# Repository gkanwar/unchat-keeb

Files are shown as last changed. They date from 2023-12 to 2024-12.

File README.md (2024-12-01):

# Overview
This repository contains the design materials, firmware, and related docs for
two iterations (2023 and 2024) of the **"Unchat" keyboard**.  Highlights of this
design include:

 * An **ergonomic, split form keyboard** with 40 keys (2024) or 42 keys (2023)
 * **Custom Rust firmware** supporting QMK JSON keymaps using a limited feature set
 * **Hardware chatter mitigation** through Hall Effect magnetic switches (2024)
   or hardware debouncing circuitry (2023)
 * **Diode-free** using a 6-bit bus (2023) or 4-bit analog muxes (2024)

Here are some photos.

The **Unchat-42 (2023)**:
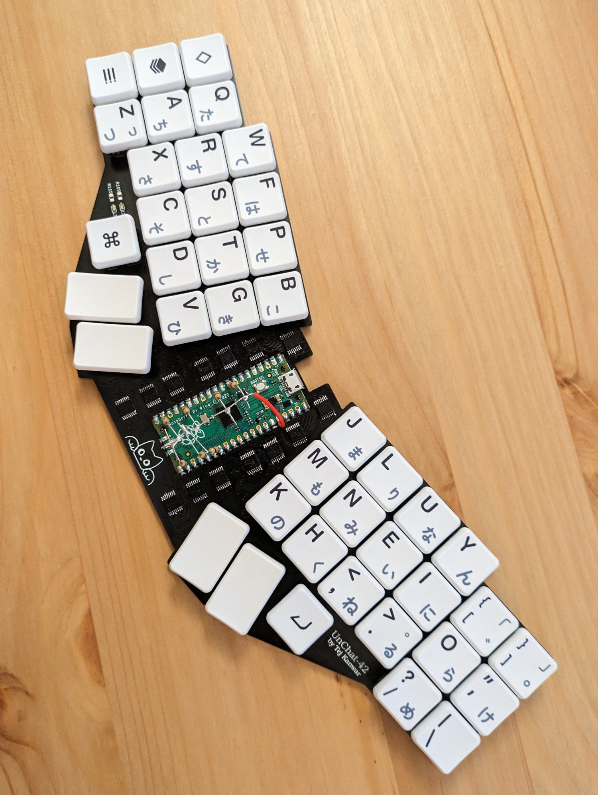
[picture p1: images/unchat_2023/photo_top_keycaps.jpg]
Top view of assembled 2023 kbd

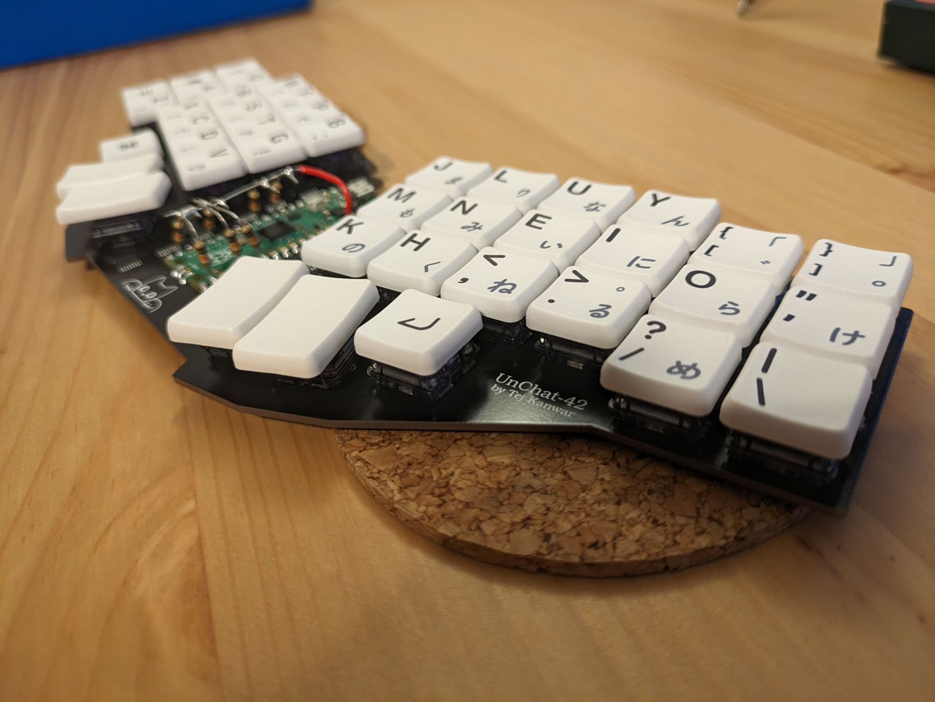
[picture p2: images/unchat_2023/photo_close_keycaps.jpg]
Close-up image of assembled 2023 kbd


Designing the PCB in Kicad and the results:
PCB design in Kicad
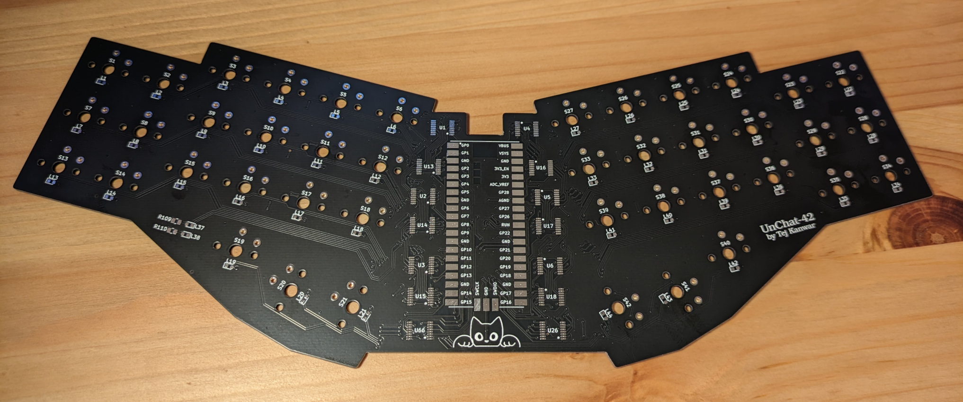
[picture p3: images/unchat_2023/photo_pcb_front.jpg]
Front view of 2023 pcb

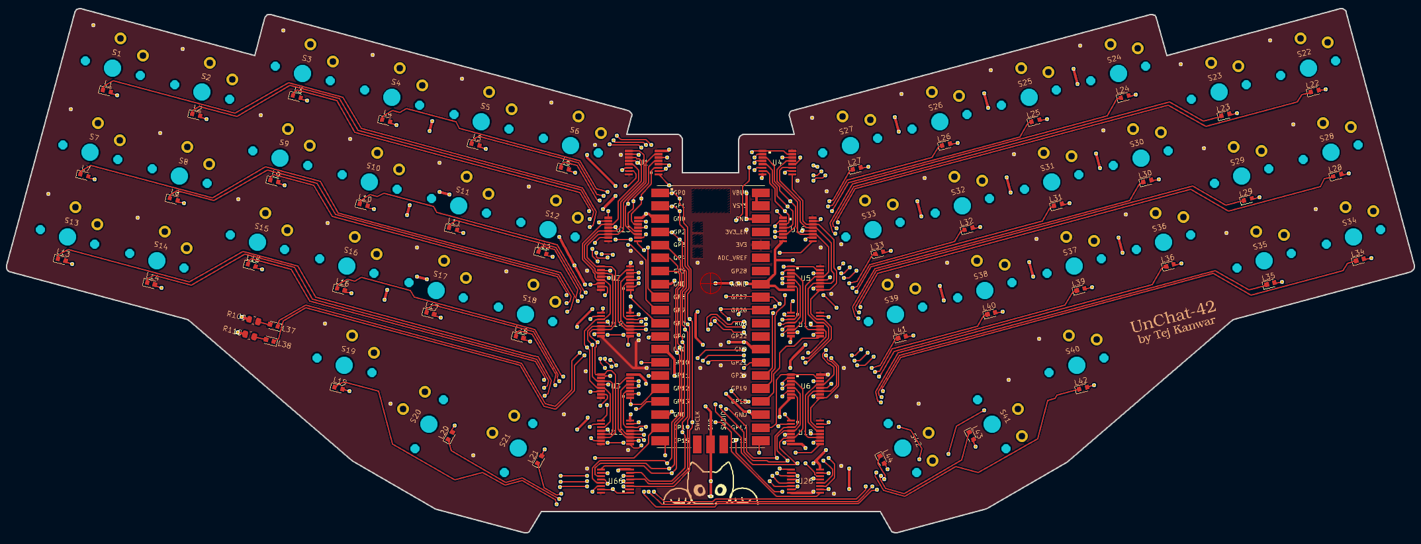
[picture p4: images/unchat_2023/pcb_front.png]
Front view of 2023 pcb design

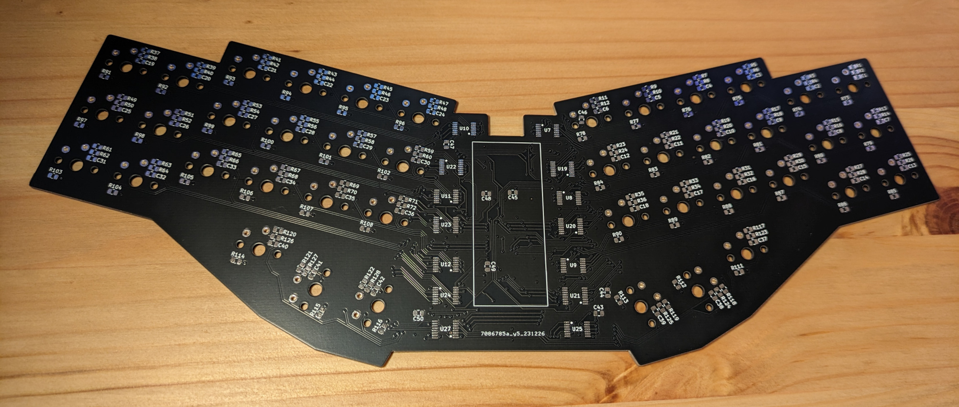
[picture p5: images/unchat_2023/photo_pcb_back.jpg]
Back view of 2023 pcb

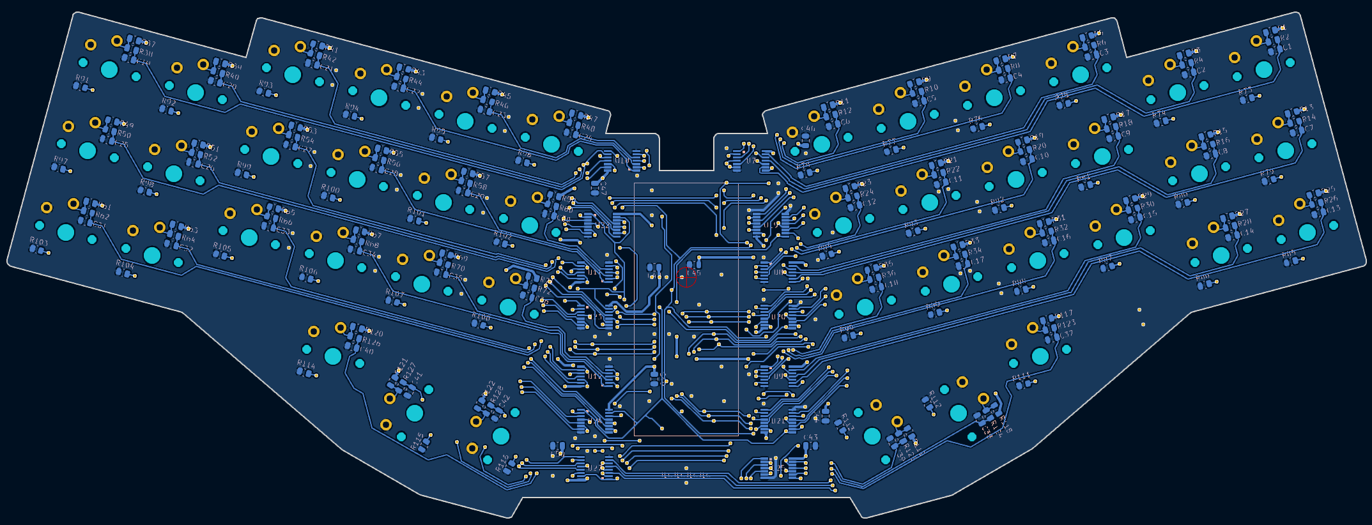
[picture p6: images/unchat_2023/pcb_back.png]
Back view of 2023 pcb design


The **Unchat-40 (2024)** (assembly still WIP):
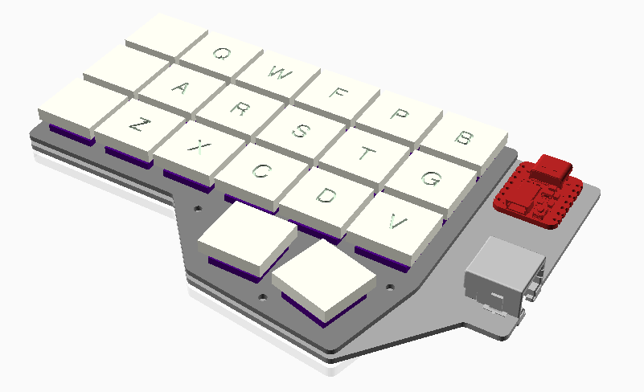
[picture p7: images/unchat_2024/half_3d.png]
3D design overview

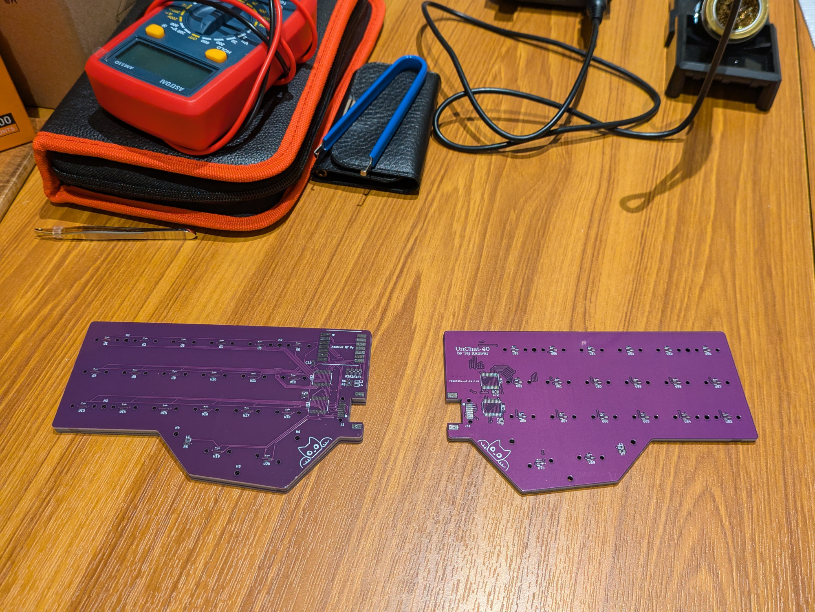
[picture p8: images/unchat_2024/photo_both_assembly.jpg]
Top view of assembled 2023 pcbs

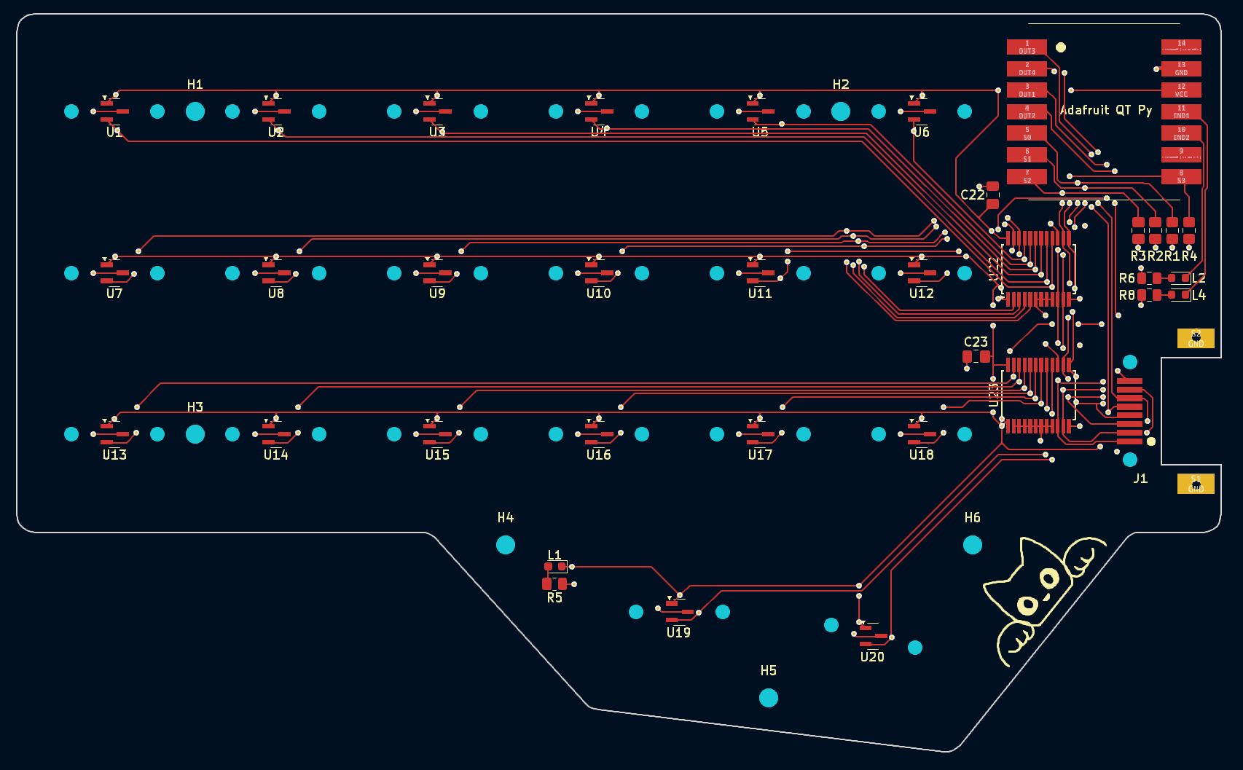
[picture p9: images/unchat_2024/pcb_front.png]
Front view of 2023 pcb

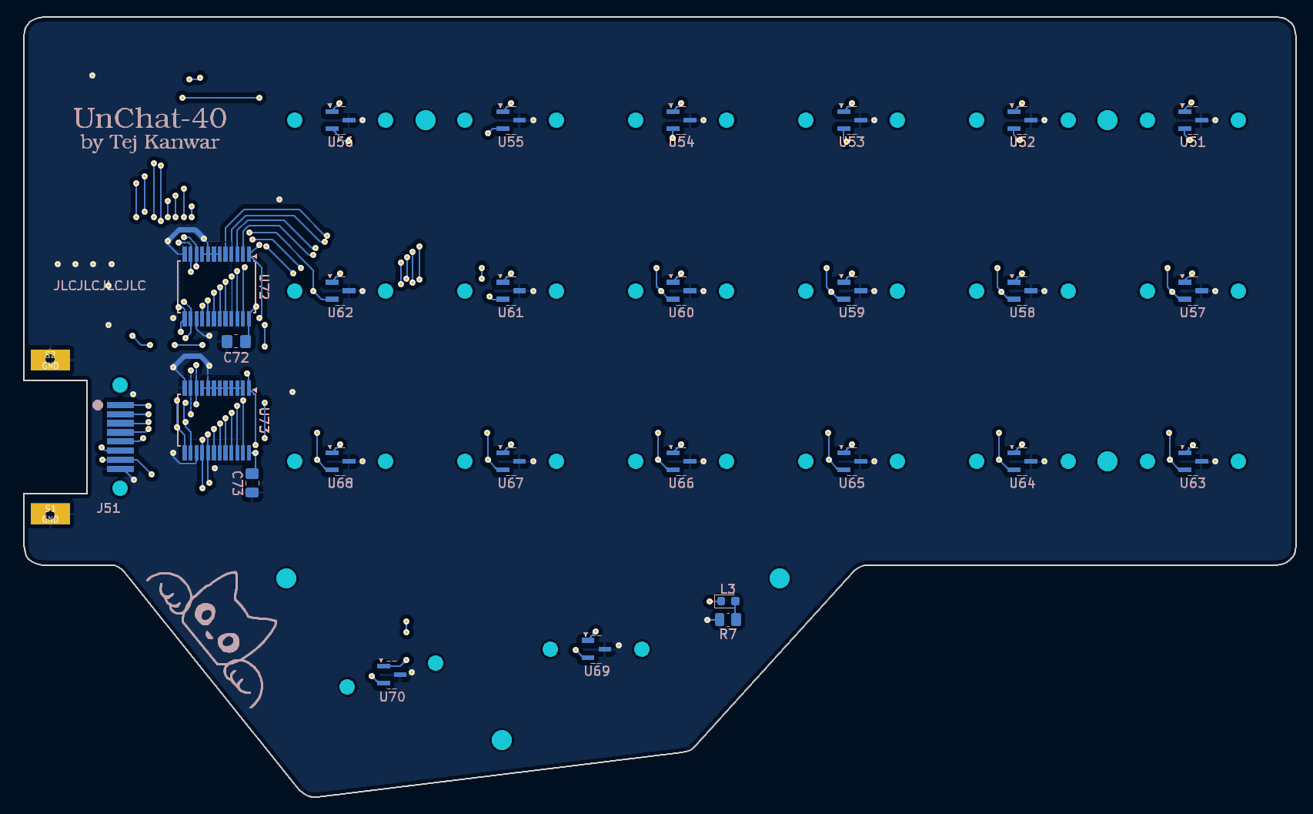
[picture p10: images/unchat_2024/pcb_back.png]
Back view of 2023 pcb


## Why design a custom keyboard?
This project was motivated in small part by wanting to solve frustrating key
chatter on my main keyboard and in larger part as a way to kill free time during
holiday seasons. It was an awesome way to learn several new skills. I recommend
this sort of project if any of these interest you as well:

 * PCB design in Kicad
 * Mechanical design in OpenSCAD
 * Electronic assembly and debugging
 * Embedded Rust

## Free to use and share
Designs and code in this repository are covered by the CC0 license, allowing
anyone to freely copy, modify, or distribute these materials. Attribution not
required.

That said, there are some known issues with the original designs. These are
documented below, along with my workarounds. In some cases, these issues are
corrected in the latest design files, but corrections have not been tested. You
may discover other issues that I have not personally encountered. **Use at your
own risk!**

# Unchat-40 (2024)

## Design overview
Summary of design features:

 * Two **reversible PCBs** connected via RJ45
 * Controlled by an **Adafruit QT Py RP2040**
 * **Hall-effect** switches queried via **analog muxes**
 * Acrylic and/or aluminum plate and frame

The 2023 design was fairly successful at reducing key chatter without software
debouncing, but I still experienced occasional chatter (see below).
Unfortunately, this was on timescales far above the filtering provided by the
hardware debouncing, likely due to corrosion and mechanical deformation in the
switches due to my terrible assembly process.

With this new 2024 design, I entirely circumvented using electrical contacts by
moving to a Hall Effect magnetic switch design. This is also used in some
"gaming-friendly" keyboards because it allows very rapid triggering, but from
the perspective of this design the main advantage is that we can apply
**hysteresis** to completely eliminate chatter. The cheap DRV5055 sensor
fit the design perfectly. Unfortunately, magnetic switches are still fairly
rare and a bit more pricey, but the overall cost was still manageable.

## Electronic design

## Mechanical design

## Cost breakdown

# Unchat-42 (2023)

More design info and post-mortem coming soon!

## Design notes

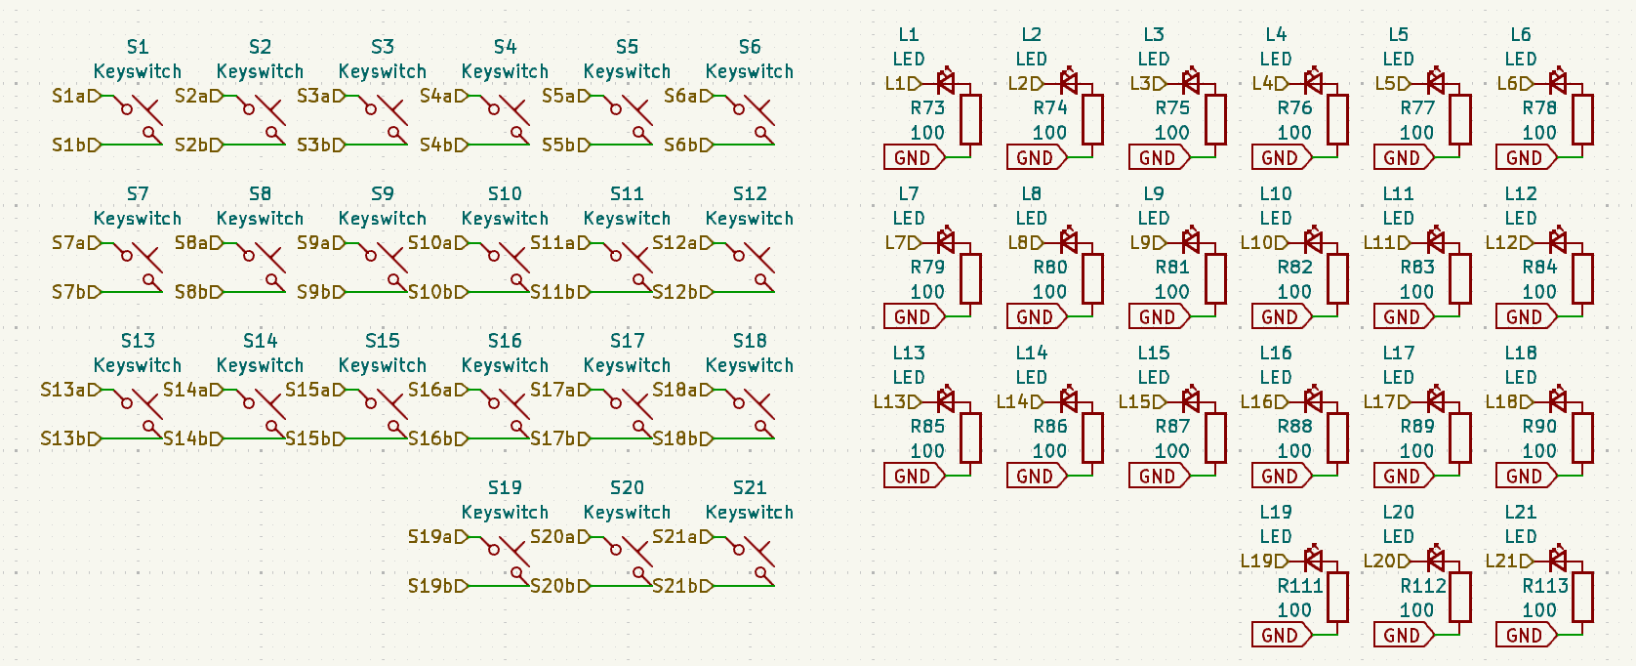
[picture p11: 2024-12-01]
images/unchat_2023/schematic_switches_leds.png

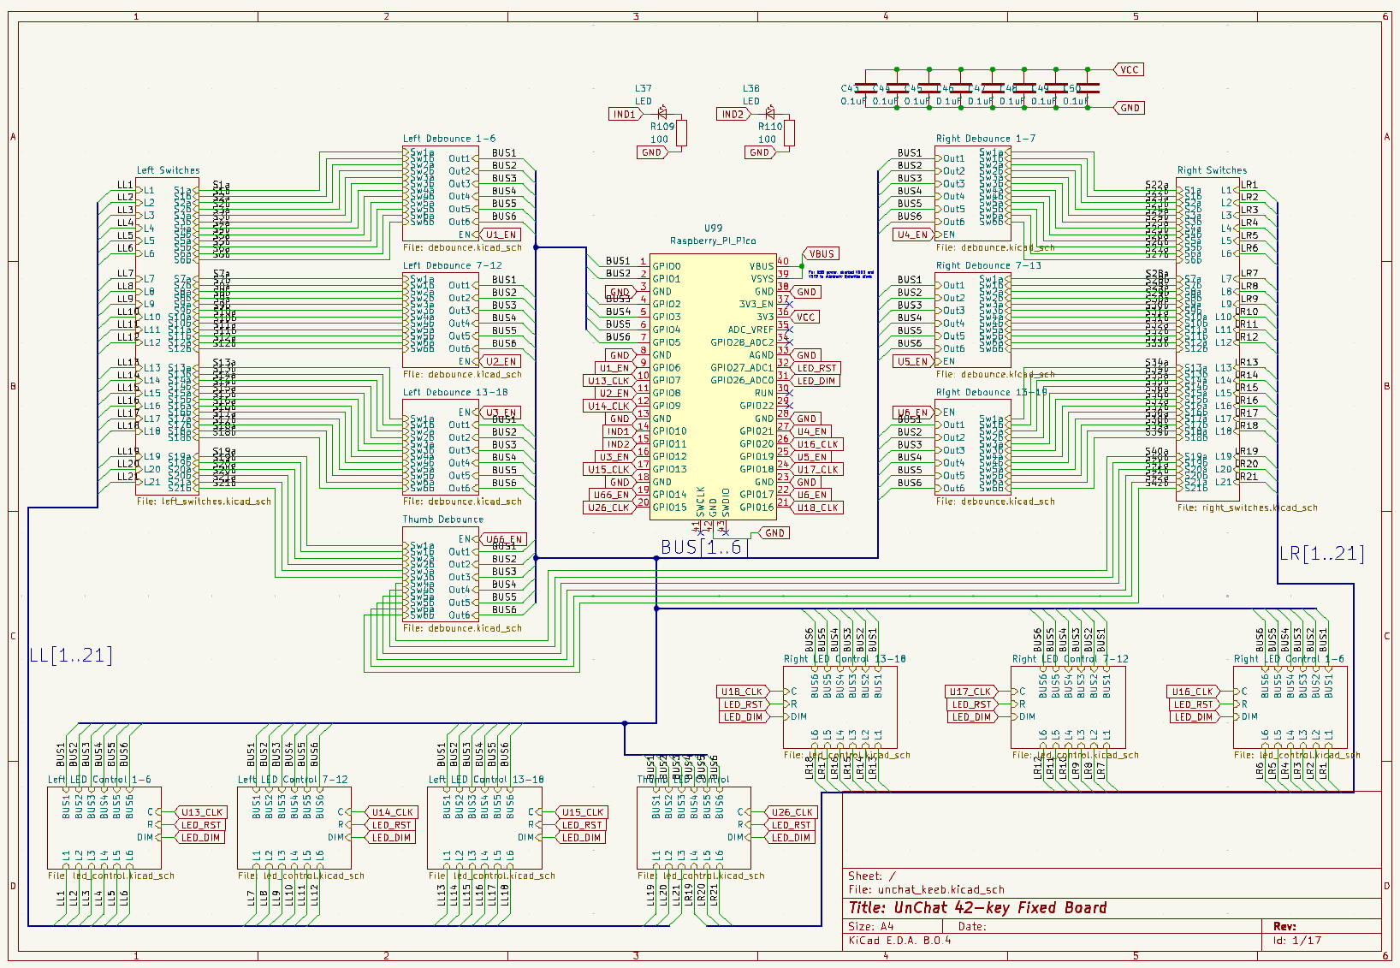
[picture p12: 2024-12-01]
images/unchat_2023/schematic_overview.png

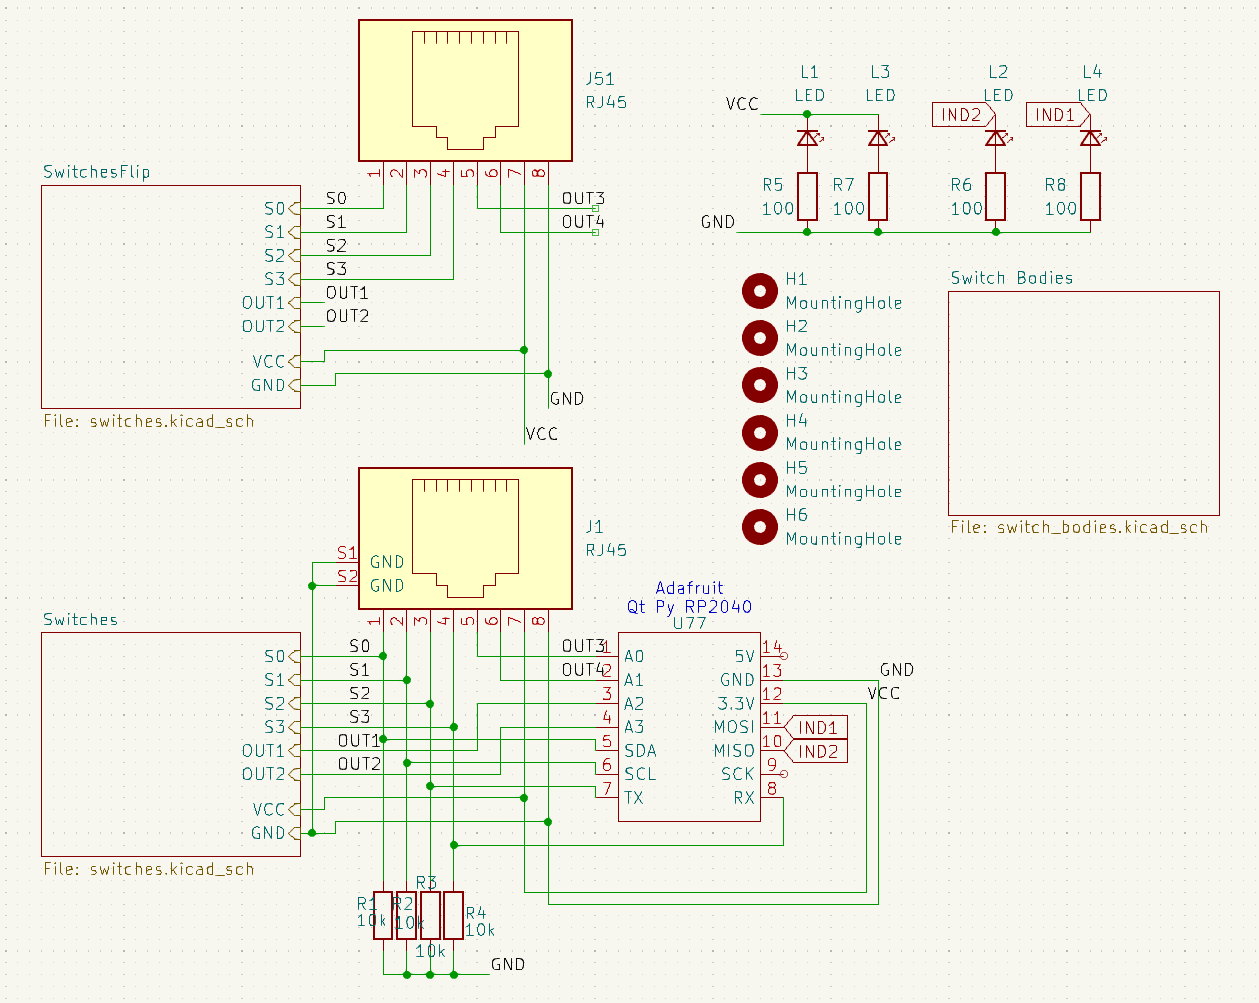
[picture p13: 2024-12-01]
images/unchat_2024/schematic_overview.png

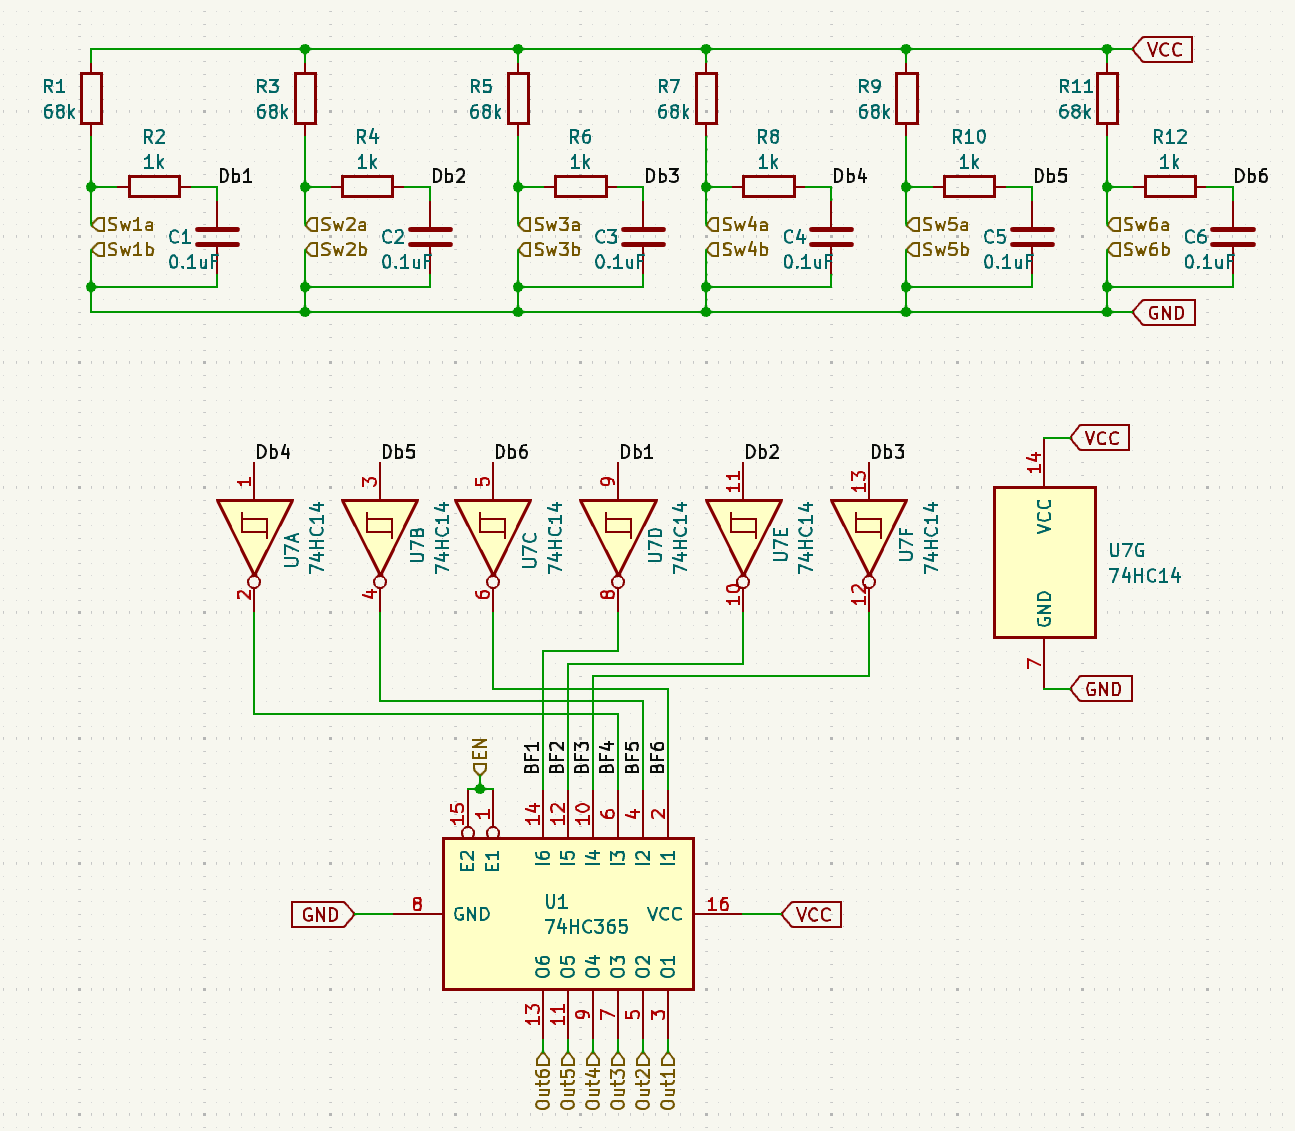
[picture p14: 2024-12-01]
images/unchat_2023/schematic_debounce.png

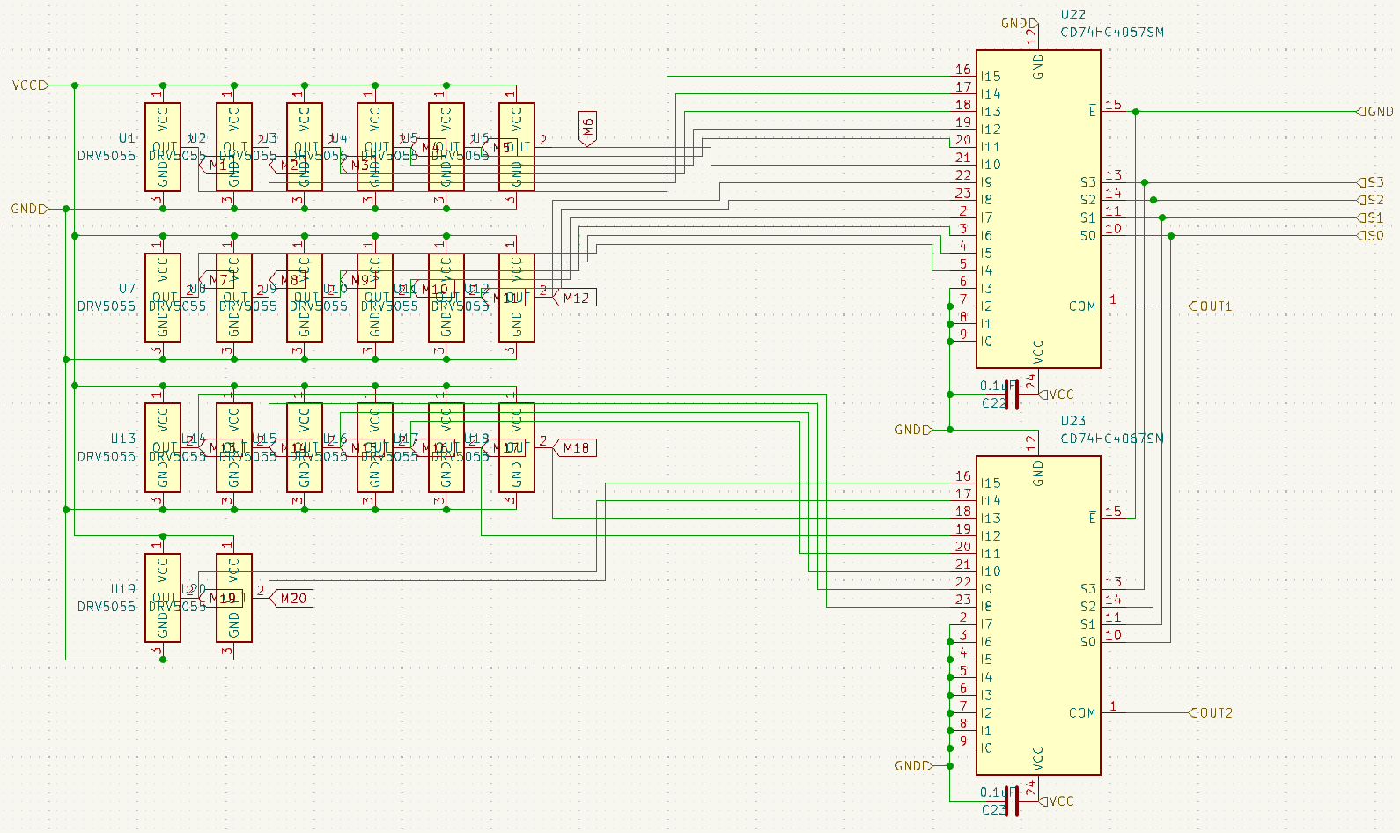
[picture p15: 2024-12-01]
images/unchat_2024/schematic_switches.png

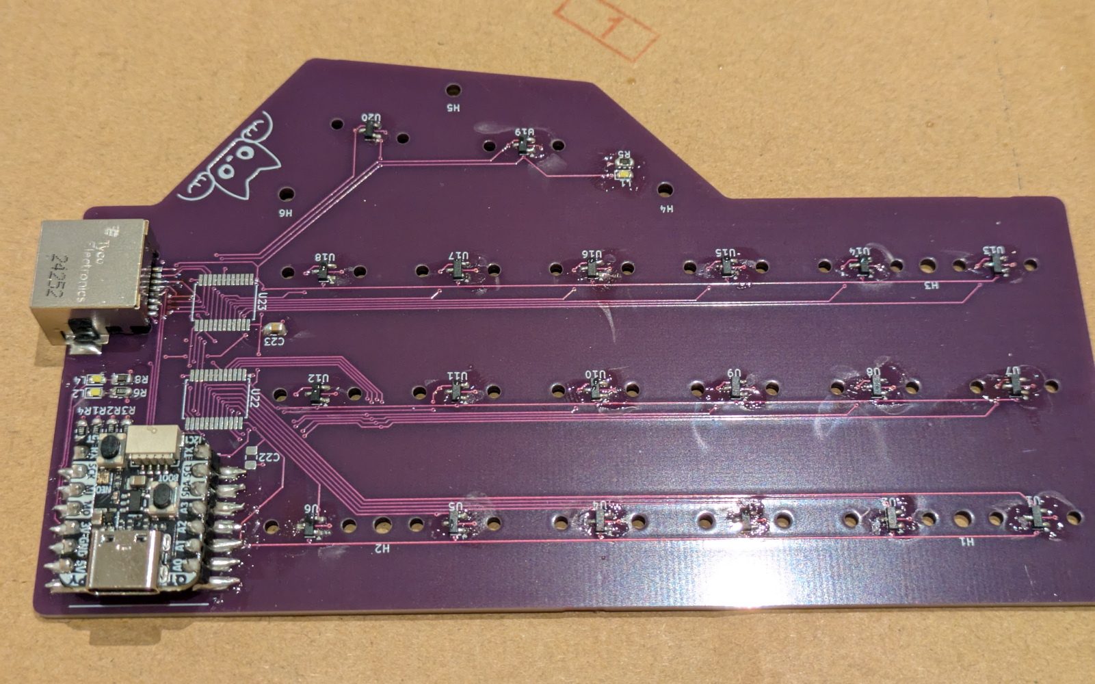
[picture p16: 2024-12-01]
images/unchat_2024/photo_lhs_no_keycaps.jpg

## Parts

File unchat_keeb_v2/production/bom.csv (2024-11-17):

Designator | Footprint | Quantity | Value | LCSC Part #
C22, C23, C72, C73 | 0805 | 4 | 0.1uF
J1 | TE_2041126-1_RJ45 | 1 | RJ45
J51 | TE_2041126-1_RJ45_Back | 1 | RJ45
L1, L2, L3, L4 | 0603 | 4 | LED
R1, R2, R3, R4 | 0805 | 4 | 10k
R5, R6, R7, R8 | 0805 | 4 | 100
S1, S10, S11, S12, S13, S14, S15, S16, S17, S18, S19, S2, S20, S3, S4, S5, S6, S7, S8, S9 | MX_HallEffect_Reversible_1.00u | 20 | Keyswitch
U1, U10, U11, U12, U13, U14, U15, U16, U17, U18, U19, U2, U20, U3, U4, U5, U51, U52, U53, U54, U55, U56, U57, U58, U59, U6, U60, U61, U62, U63, U64, U65, U66, U67, U68, U69, U7, U70, U8, U9 | SOT-23 | 40 | DRV5055
U22, U23, U72, U73 | SSOP-24_5.3x8.2mm_P0.65mm | 4 | CD74HC4067SM
U77 | Adafruit_QT_Py_SMD | 1 | ~

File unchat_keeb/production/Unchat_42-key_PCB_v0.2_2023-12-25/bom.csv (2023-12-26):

Designator | Footprint | Quantity | Value | LCSC Part #
C1, C10, C11, C12, C13, C14, C15, C16, C17, C18, C19, C2, C20, C21, C22, C23, C24, C25, C26, C27, C28, C29, C3, C30, C31, C32, C33, C34, C35, C36, C37, C38, C39, C4, C40, C41, C42, C43, C44, C45, C46, C47, C48, C49, C5, C50, C6, C7, C8, C9 | 0805 | 50 | 0.1uF
L1, L10, L11, L12, L13, L14, L15, L16, L17, L18, L19, L2, L20, L21, L22, L23, L24, L25, L26, L27, L28, L29, L3, L30, L31, L32, L33, L34, L35, L36, L37, L38, L39, L4, L40, L41, L42, L43, L44, L5, L6, L7, L8, L9 | 0603 | 44 | LED
R1, R11, R117, R118, R119, R120, R121, R122, R13, R15, R17, R19, R21, R23, R25, R27, R29, R3, R31, R33, R35, R37, R39, R41, R43, R45, R47, R49, R5, R51, R53, R55, R57, R59, R61, R63, R65, R67, R69, R7, R71, R9 | 0805 | 42 | 68k
R10, R12, R123, R124, R125, R126, R127, R128, R14, R16, R18, R2, R20, R22, R24, R26, R28, R30, R32, R34, R36, R38, R4, R40, R42, R44, R46, R48, R50, R52, R54, R56, R58, R6, R60, R62, R64, R66, R68, R70, R72, R8 | 0805 | 42 | 1k
R100, R101, R102, R103, R104, R105, R106, R107, R108, R109, R110, R111, R112, R113, R114, R115, R116, R73, R74, R75, R76, R77, R78, R79, R80, R81, R82, R83, R84, R85, R86, R87, R88, R89, R90, R91, R92, R93, R94, R95, R96, R97, R98, R99 | 0805 | 44 | 100
S1, S10, S11, S12, S13, S14, S15, S16, S17, S18, S19, S2, S22, S23, S24, S25, S26, S27, S28, S29, S3, S30, S31, S32, S33, S34, S35, S36, S37, S38, S39, S4, S40, S5, S6, S7, S8, S9 | Choc_V1_LED_1.00u | 38 | Keyswitch
S20, S21, S41, S42 | Choc_V1_LED_1.50u | 4 | Keyswitch
U1, U19, U2, U20, U21, U22, U23, U24, U27, U3, U4, U5, U6, U66 | TSSOP-16_4.4x5mm_P0.65mm | 14 | 74HC365
U10, U11, U12, U25, U7, U8, U9 | TSSOP-14_4.4x5mm_P0.65mm | 7 | 74HC14
U13, U14, U15, U16, U17, U18, U26 | TSSOP-16_4.4x5mm_P0.65mm | 7 | 74HC174
U99 | Raspberry_Pi_Pico_SMD | 1 | Raspberry_Pi_Pico

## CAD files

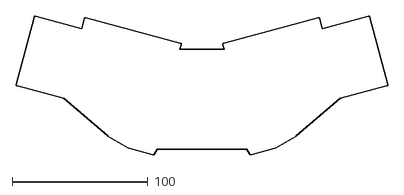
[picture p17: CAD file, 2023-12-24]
cad/pcb.dxf
274.1 x 102.0

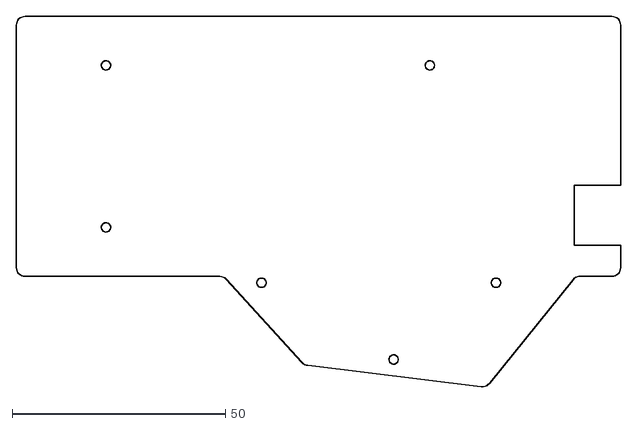
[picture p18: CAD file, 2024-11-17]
cad_v2/pcb.dxf
141.8 x 86.9

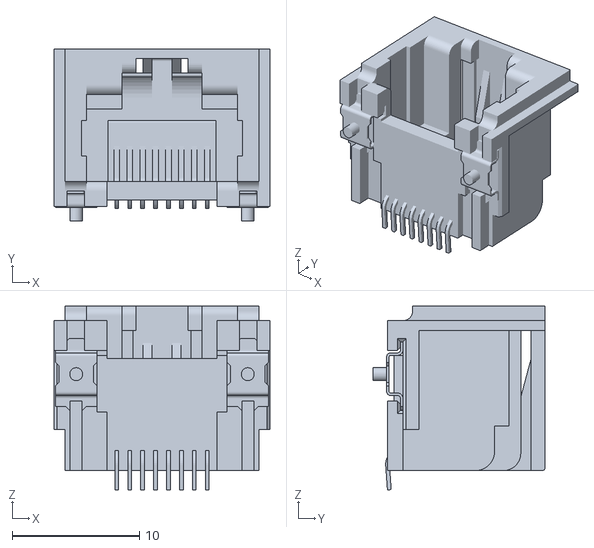
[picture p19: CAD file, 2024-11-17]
components/rj45-5406721.stl
17.0 x 13.5 x 14.5

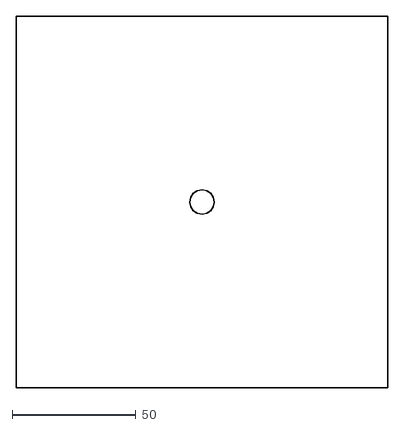
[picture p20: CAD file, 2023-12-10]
unchat_keeb/bottom_plate.dxf
150.0 x 150.0

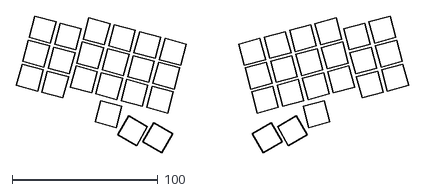
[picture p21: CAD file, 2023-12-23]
cad/switches.dxf
268.6 x 93.4

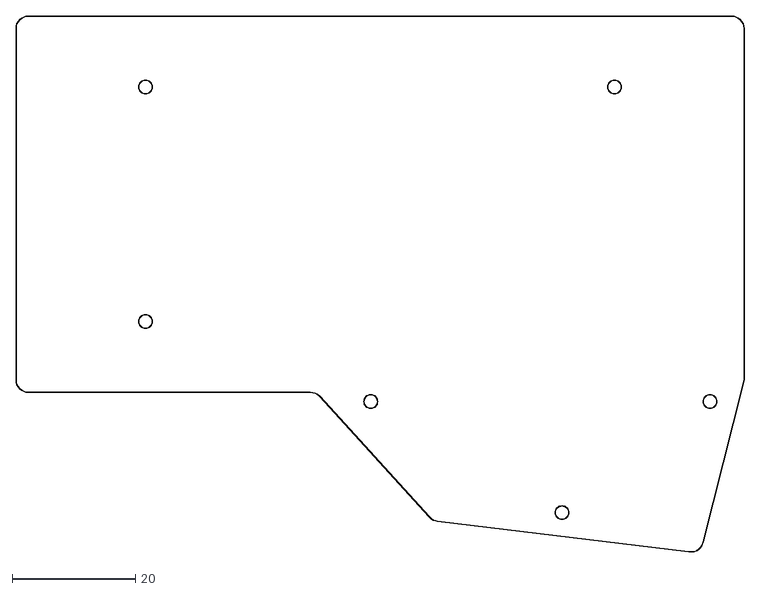
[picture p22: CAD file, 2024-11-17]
cad_v2/bottom_plate.dxf
118.0 x 86.9

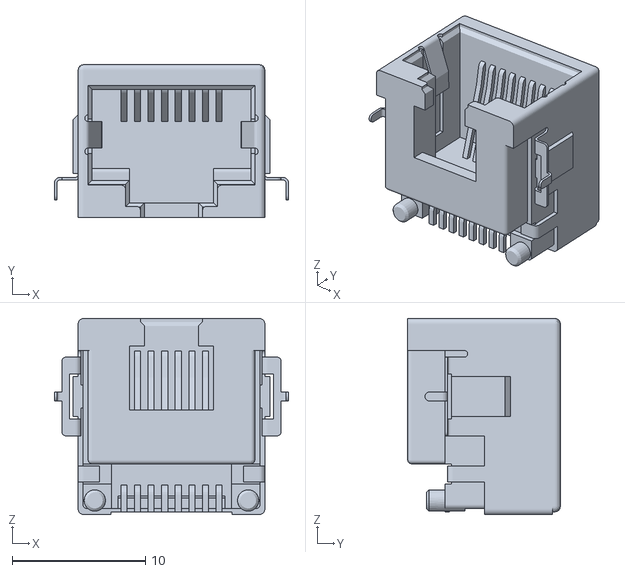
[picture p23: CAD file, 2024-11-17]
components/rj45-2041126-1.stl
17.5 x 11.5 x 14.7

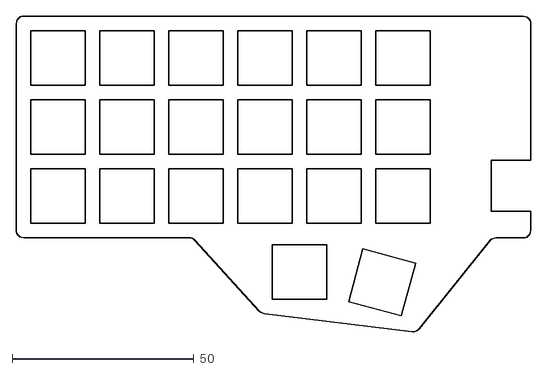
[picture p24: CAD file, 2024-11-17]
cad_v2/plate.dxf
141.8 x 86.9

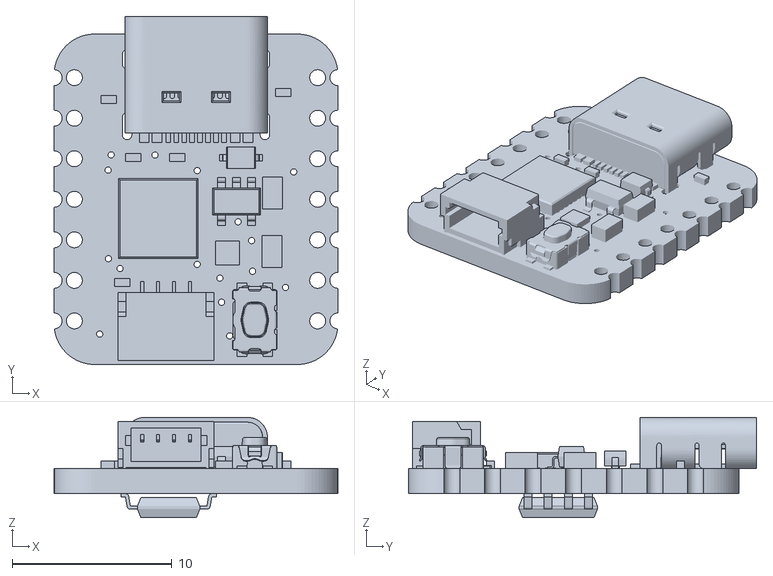
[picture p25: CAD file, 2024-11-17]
components/4600 QTPy.step.stl
17.8 x 21.8 x 6.28

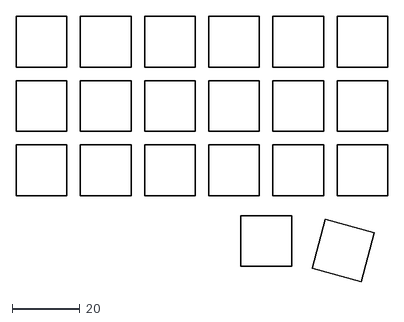
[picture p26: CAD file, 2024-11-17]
cad_v2/switches.dxf
110.0 x 78.4

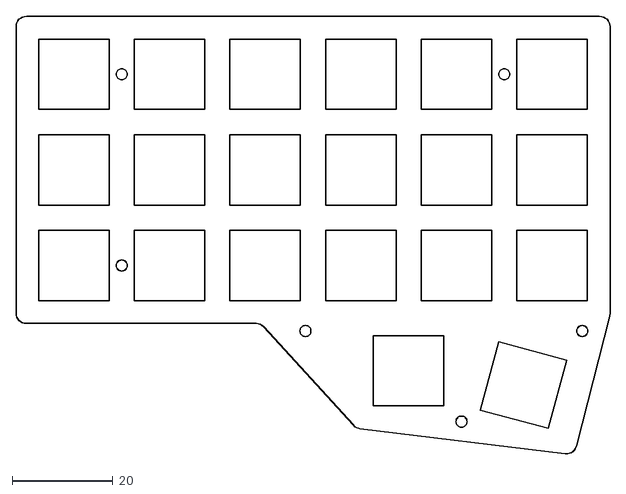
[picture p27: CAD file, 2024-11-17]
cad_v2/top_plate.dxf
118.0 x 86.9

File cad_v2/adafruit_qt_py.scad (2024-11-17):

module qtpy() {
  inch_to_mm = 25.4;
  translate([-inch_to_mm*0.70/2, -inch_to_mm*0.81/2, 0])
  color("FireBrick")
  import("../components/4600 QTPy.step.stl");
}

qtpy();

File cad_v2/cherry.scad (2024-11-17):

module cherry(c="Indigo") {
  // $fs = 0.02;
  color(c)
  difference() {
    translate([0,0,2.5])
    cube([14, 14, 5], center=true);
    // cylinder(h=1, d=3.40, center=true);
  }
}

module cherry_1u_kc(c="Ivory") {
  color(c)
  translate([0,0,1.85])
  cube([17.5, 16.5, 3.7], center=true);
}

module cherry_1u(s="", c="Ivory", with_kc=true) {
  cherry();
  if (with_kc) {
    translate([0,0,7])
    difference() {
      cherry_1u_kc(c=c);
      translate([0,0,3.5]) text(s, size=5, halign="center", valign="center");
    }
  }
}

cherry_1u("A");
translate([20,0,0])
cherry_1u(with_kc=false);

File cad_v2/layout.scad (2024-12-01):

use <cherry.scad>;
use <adafruit_qt_py.scad>;
use <rj45.scad>;

cdx = 19;
cdy = 19;

$fn = 32;

module cherry_1u_array(nx, ny, letters, with_kc) {
  for(i = [0:nx-1]) {
    for(j = [0:ny-1]) {
      translate([i*cdx, j*cdy, 0])
      cherry_1u(s=letters[i + nx*(ny-j-1)], with_kc=with_kc);
    }
  }
}

module switches(with_kc=true) {
  cherry_1u_array(4, 3,
    ["W", "F", "P", "B",
    "R", "S", "T", "G",
    "X", "C", "D", "V"],
    with_kc=with_kc);
  translate([-2*cdx, 0*cdy, 0])
  cherry_1u_array(2, 3,
    [" ", "Q", " ", "A", " ", "Z"],
    with_kc=with_kc);
  translate([1.5*cdx, -1.1*cdy, 0])
  cherry_1u(with_kc=with_kc);
  translate([2.7*cdx, -1.25*cdy, 0])
  rotate(-15)
  cherry_1u(with_kc=with_kc);
}

module screwholes() {
  sd=2.2;
  translate([-13, -13, 0])
  circle(d=sd);
  translate([-68, -13, 0])
  circle(d=sd);
  translate([-37, -31, 0])
  circle(d=sd);
  translate([-5.5*cdx, 2*cdy, 0])
  circle(d=sd);
  translate([-1.5*cdx, 2*cdy, 0])
  circle(d=sd);
  translate([-5.5*cdx, 0*cdy, 0])
  circle(d=sd);
}

module outline(plate_only=false) {
  center_t2 = [(2.8+.5)*cdx, (-1.25+.5)*cdy];
  t2_rot = -15;
  cornerR_t2 = [
    center_t2[0] + 0.5*cdx*cos(t2_rot) + 0.5*cdy*sin(t2_rot),
    center_t2[1] + 0.5*cdx*sin(t2_rot) - 0.5*cdy*cos(t2_rot)
  ];
  translate([-0.5*cdx, -0.5*cdy, 0])
  union() {
    // 3x5 main area
    polygon([
      [-1*cdx,0], [4*cdx,0],
      [4*cdx,3*cdy], [-1*cdx,3*cdy]
    ]);
    if (!plate_only) {
      // electronics area
      polygon([
        [4*cdx,0], [5.25*cdx,0],
        [5.25*cdx,3*cdy], [4*cdx,3*cdy]
      ]);
      // full thumb cluster
      polygon([
        [-1*cdx,1.5*cdy], [-1*cdx,0],
        [0.5*cdx,0], [1.5*cdx,-1.1*cdy],
        cornerR_t2,
        [4.75*cdx,0*cdy], [4.75*cdx,1.5*cdy]
      ]);
    }
    else {
      // reduced thumb cluster
      polygon([
        [-1*cdx,1.5*cdy], [-1*cdx,0],
        [0.5*cdx,0], [1.5*cdx,-1.1*cdy],
        cornerR_t2,
        [4*cdx,0*cdy], [4*cdx,1.5*cdy]
      ]);
    }
    // 3x1 outermost column
    polygon([
      [-2*cdx,0*cdy],[-1*cdx,0*cdy],
      [-1*cdx,3*cdy],[-2*cdx,3*cdy]
    ]);
  }
}

hand_margin = 4*cdx;

module pcb_footprint() {
  difference() {
    translate([-hand_margin, 0, 0])
    offset(r = -2) offset(r = 4)
    outline(plate_only=false);
    union() {
      translate([0.75*cdx+2, .15*cdy, 0])
      rotate([0, 0, 90])
      rj45_footprint();
      screwholes();
    }
  }
}

module plate_footprint() {
  translate([-hand_margin, 0, 0])
  offset(r = -2) offset (r = 4)
  outline(plate_only=true);
}

module bottom_plate_outline() {
  difference() {
    plate_footprint();
    screwholes();
  }
}

module bottom_plate() {
  color("white", 0.2)
  translate([0, 0, -3])
  linear_extrude(3.0, center=false)
  bottom_plate_outline();
}

module top_plate_outline() {
  difference() {
    plate_footprint();
    union() {
      projection(cut=true)
      do_switches(with_kc=false);
      screwholes();
    }
  }
}

module top_plate() {
  color("gray")
  translate([0, 0, -1.5])
  linear_extrude(1.5, center=false)
  top_plate_outline();
}

module pcb() {
  color("darkgrey")
  translate([0, 0, -1.6])
  linear_extrude(1.6, center=false)
  pcb_footprint();
}

module do_switches(with_kc=true) {
  translate([-hand_margin, 0, 0])
  switches(with_kc=with_kc);
}

module components() {
  translate([0.15*cdy, 2*cdy, 0])
  qtpy();
  translate([.75*cdx+2, .15*cdy, 0])
  rotate([0, 0, 90])
  rj45();
}

do_switches(with_kc=true);
pcb();
components();
translate([0, 0, -3])
bottom_plate();
translate([0, 0, 3])
top_plate();

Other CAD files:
cad_v2/pcb.scad
cad/choc_v1.scad
cad/layout.scad
cad/pcb.scad
cad/pico.scad
cad_v2/rj45.scad
unchat_keeb/bottom_plate.scad

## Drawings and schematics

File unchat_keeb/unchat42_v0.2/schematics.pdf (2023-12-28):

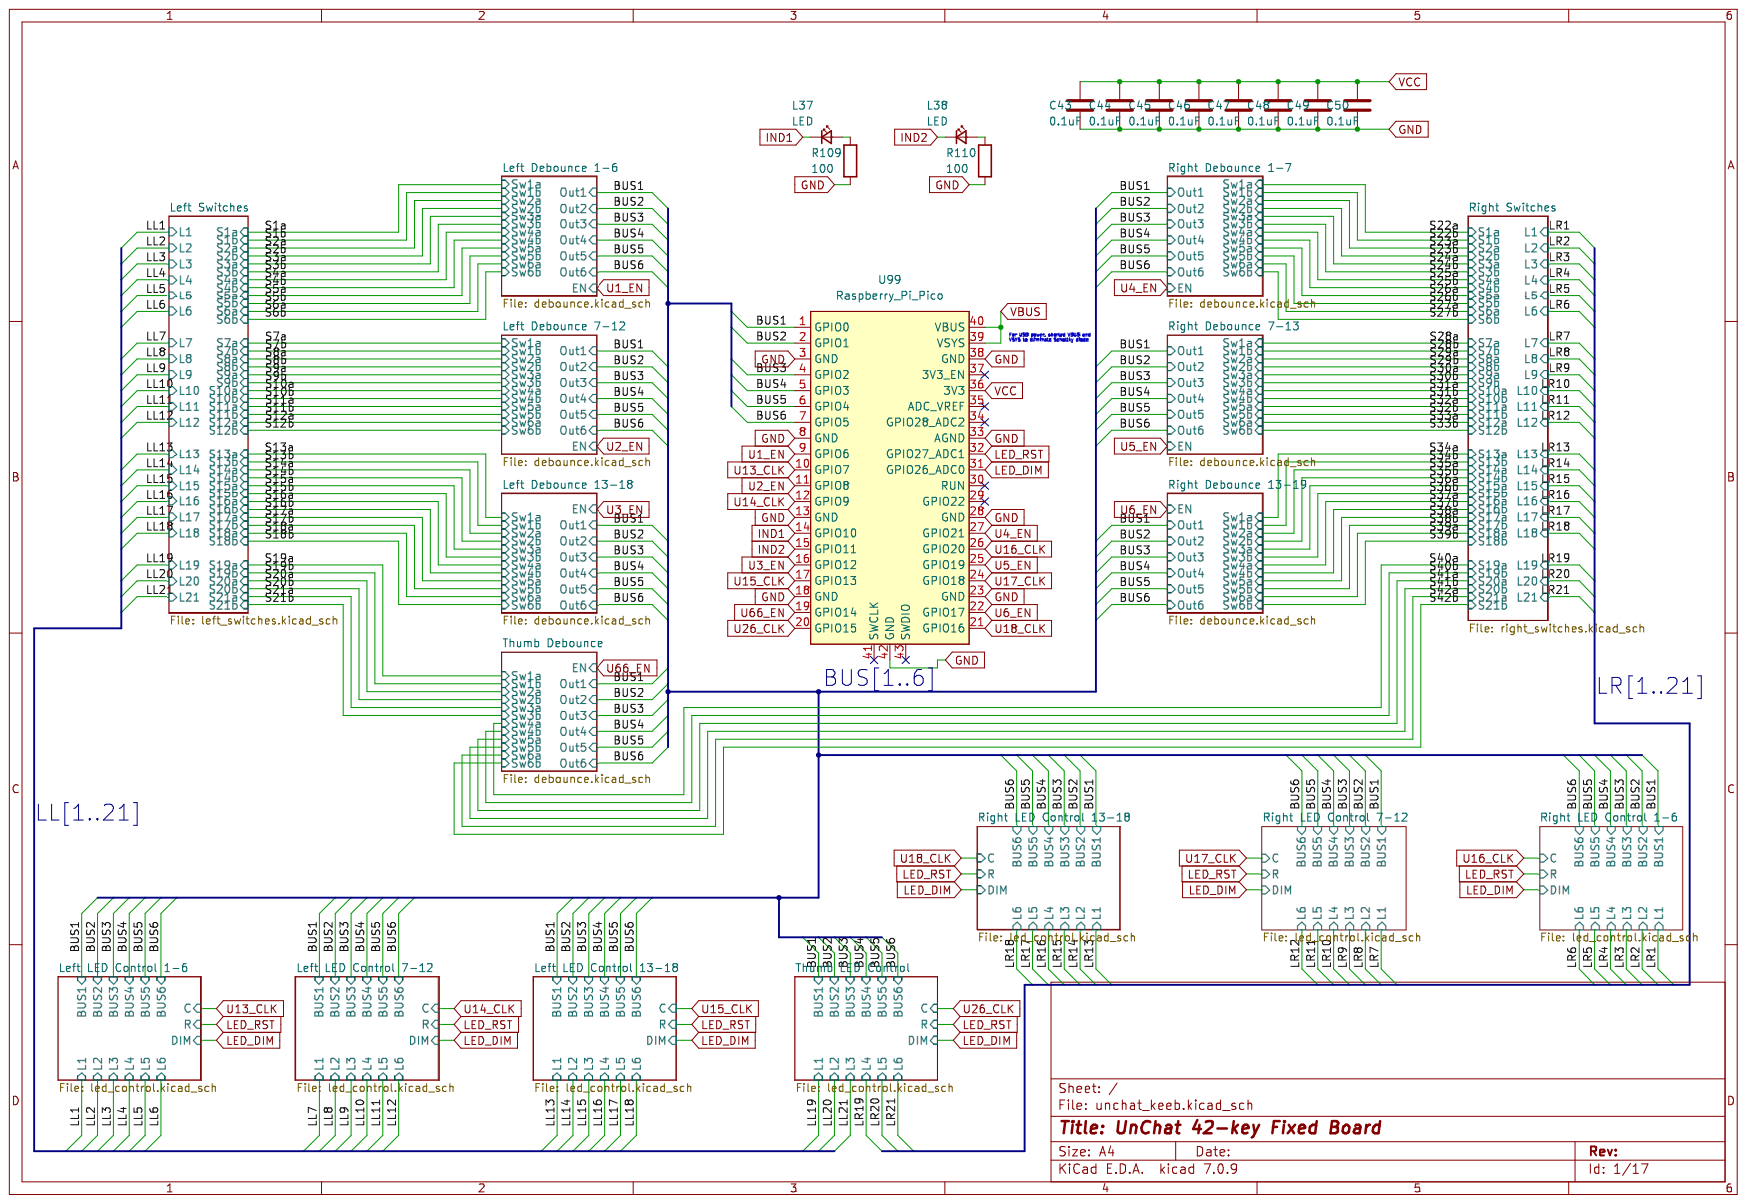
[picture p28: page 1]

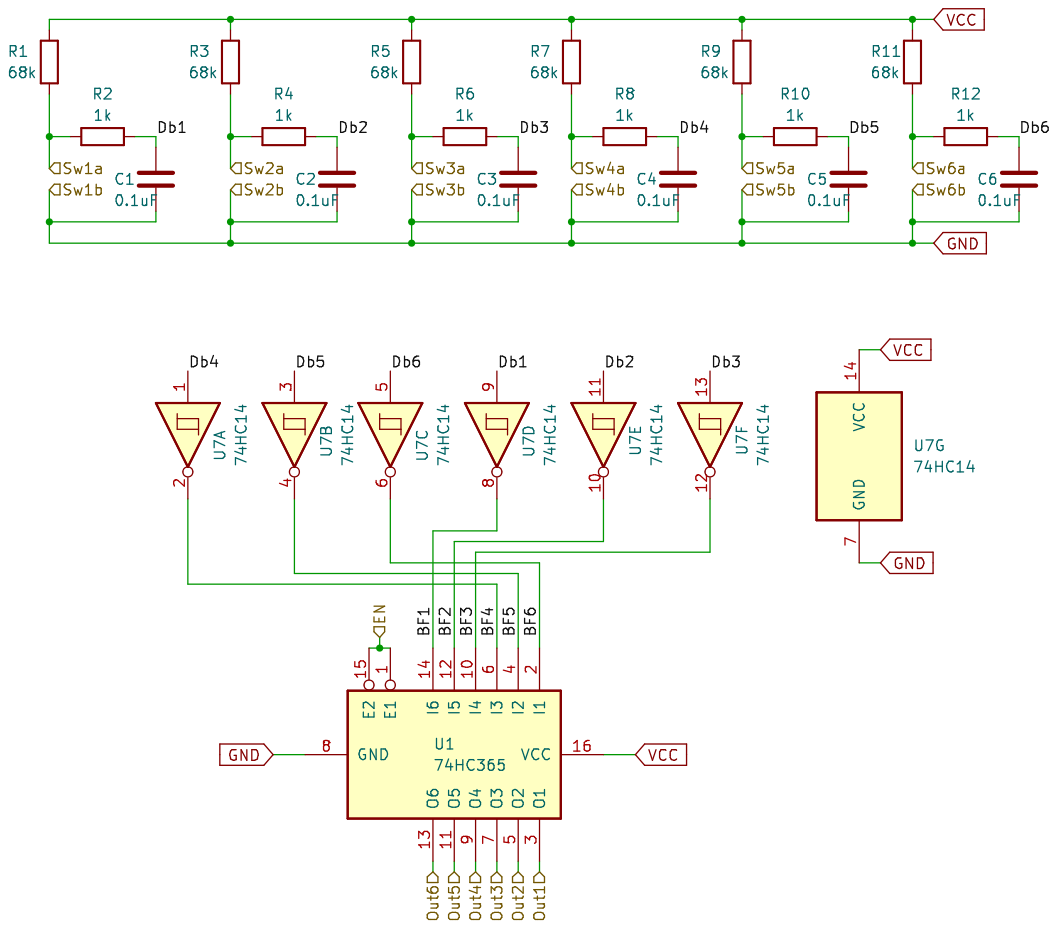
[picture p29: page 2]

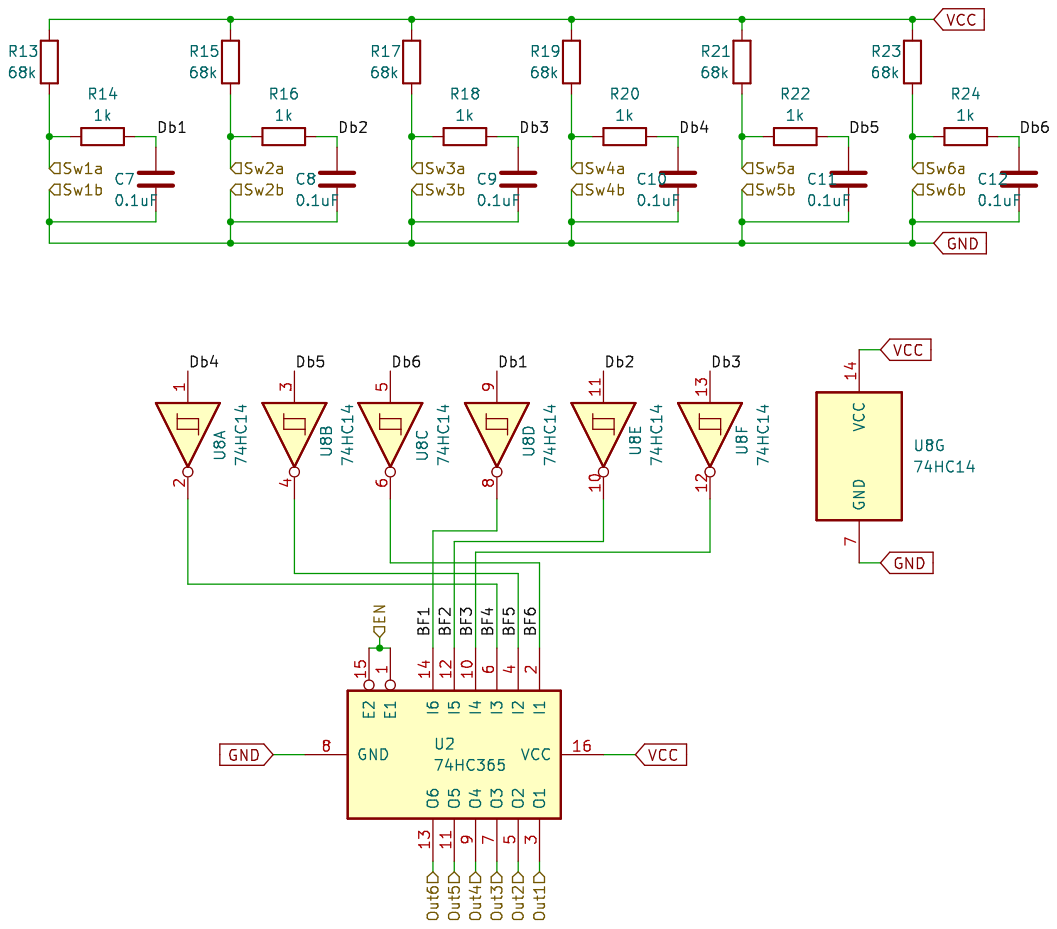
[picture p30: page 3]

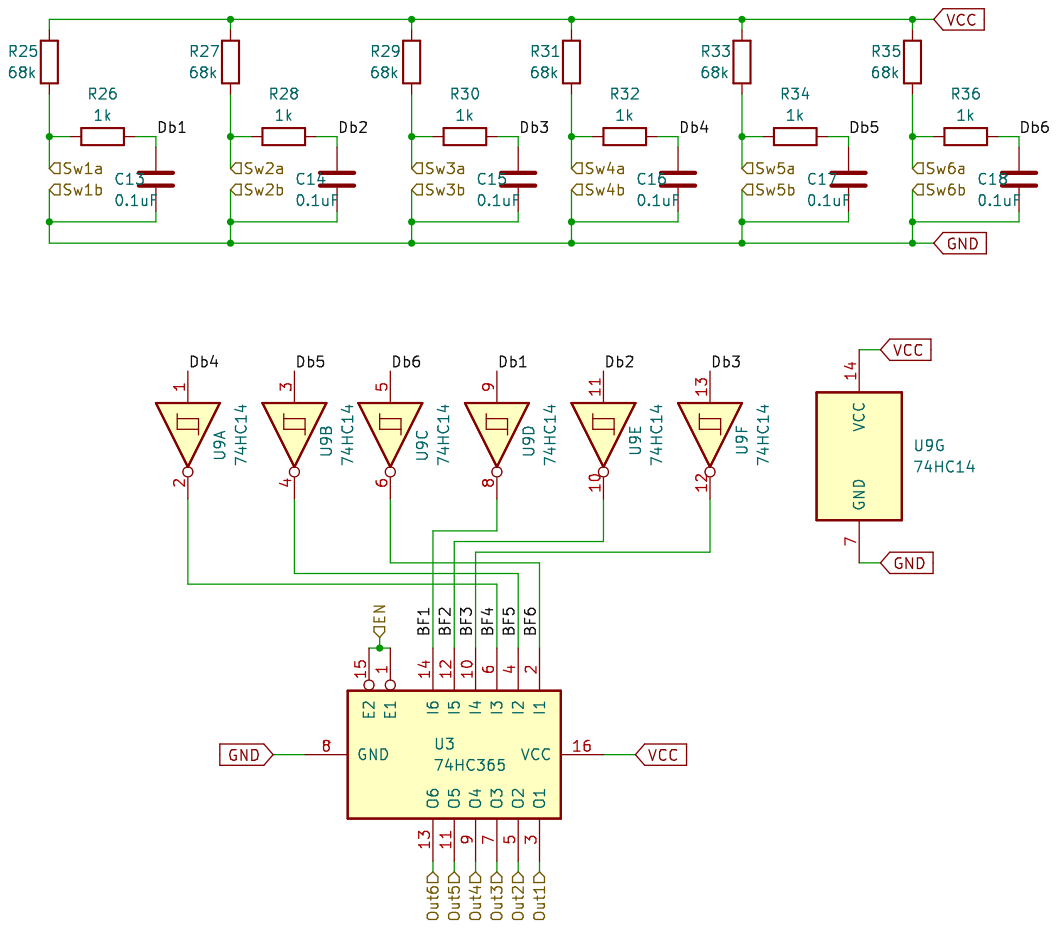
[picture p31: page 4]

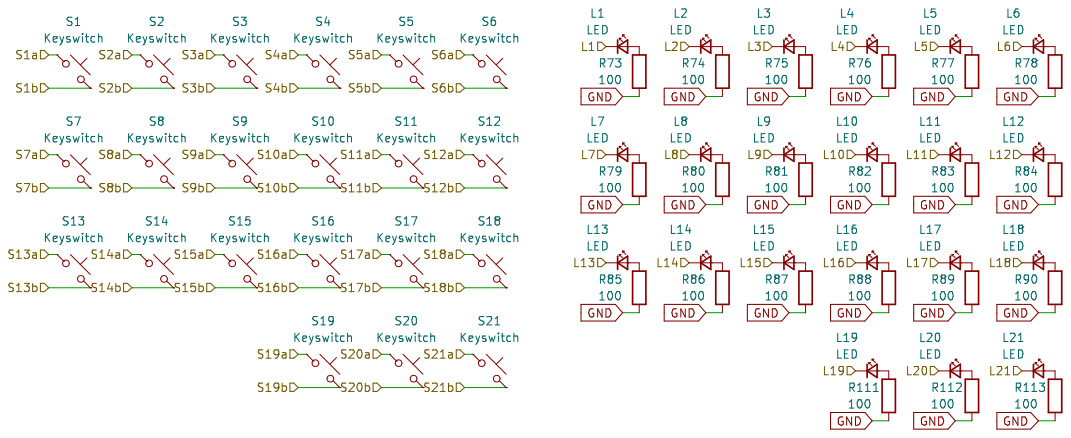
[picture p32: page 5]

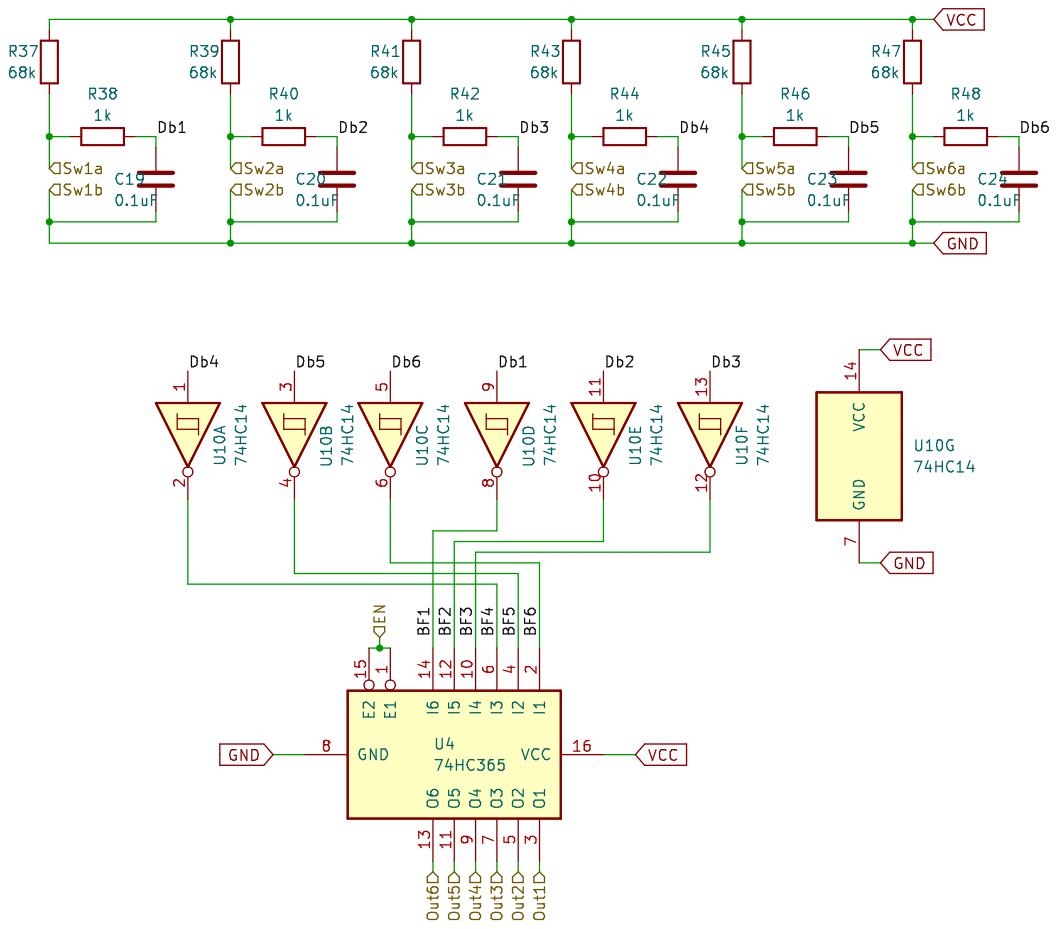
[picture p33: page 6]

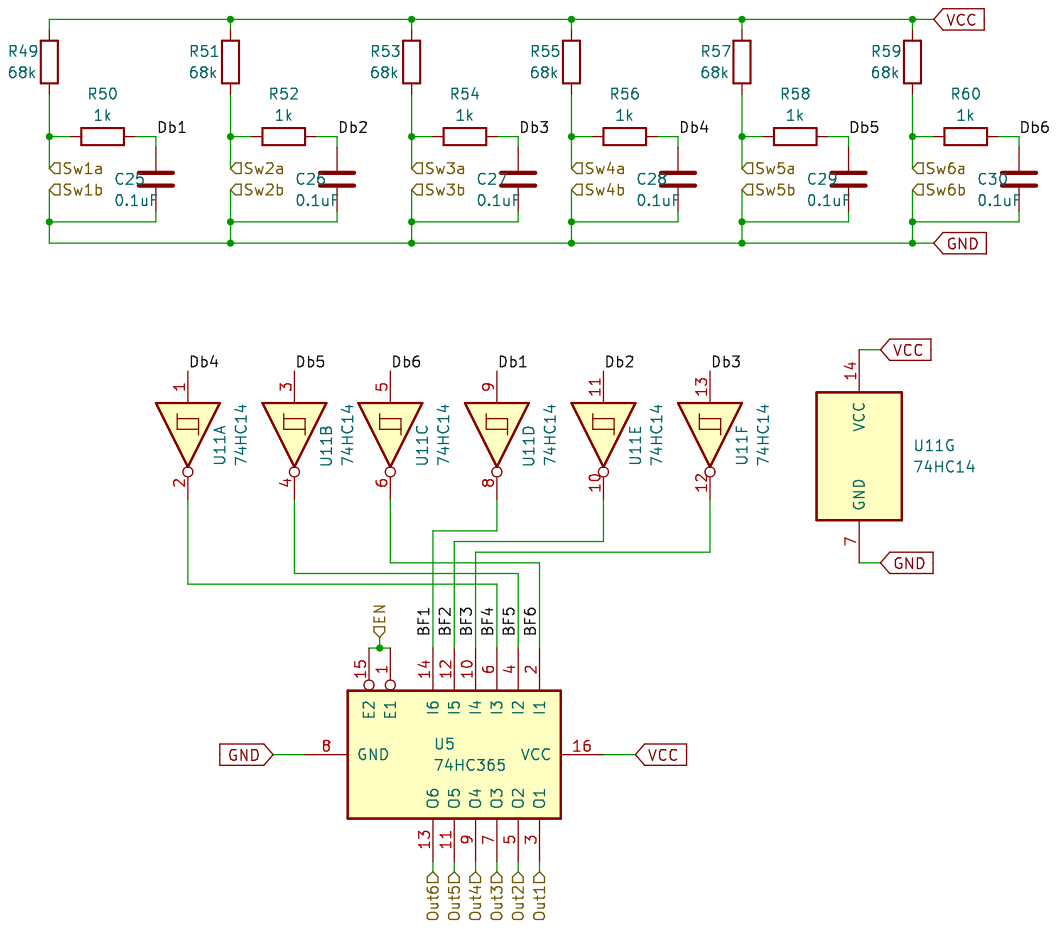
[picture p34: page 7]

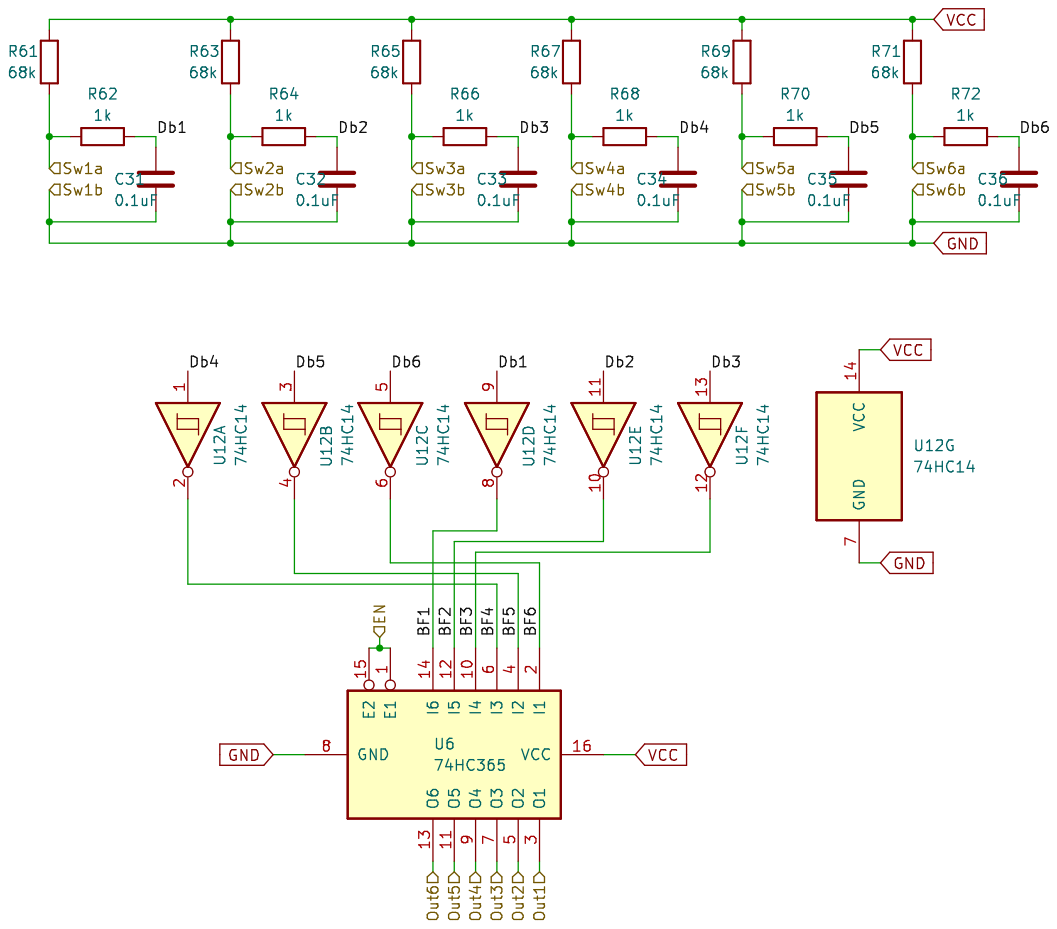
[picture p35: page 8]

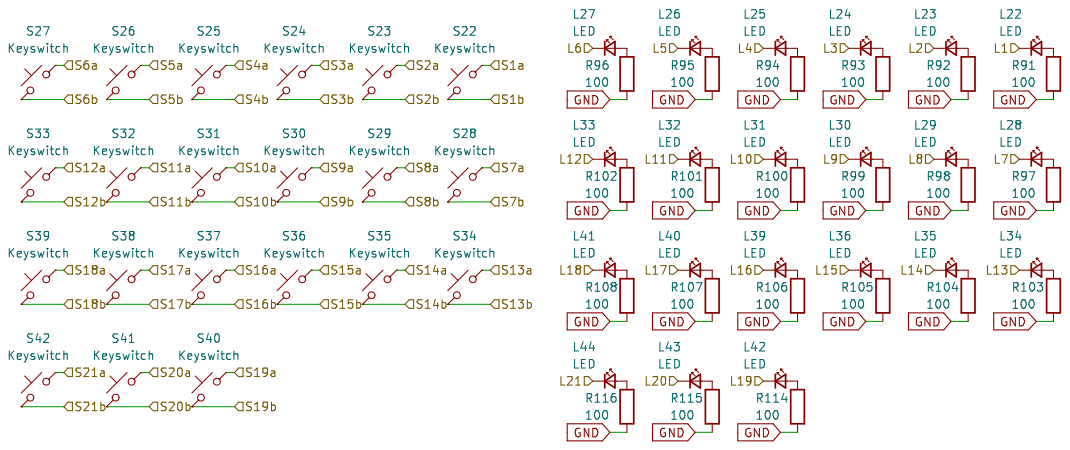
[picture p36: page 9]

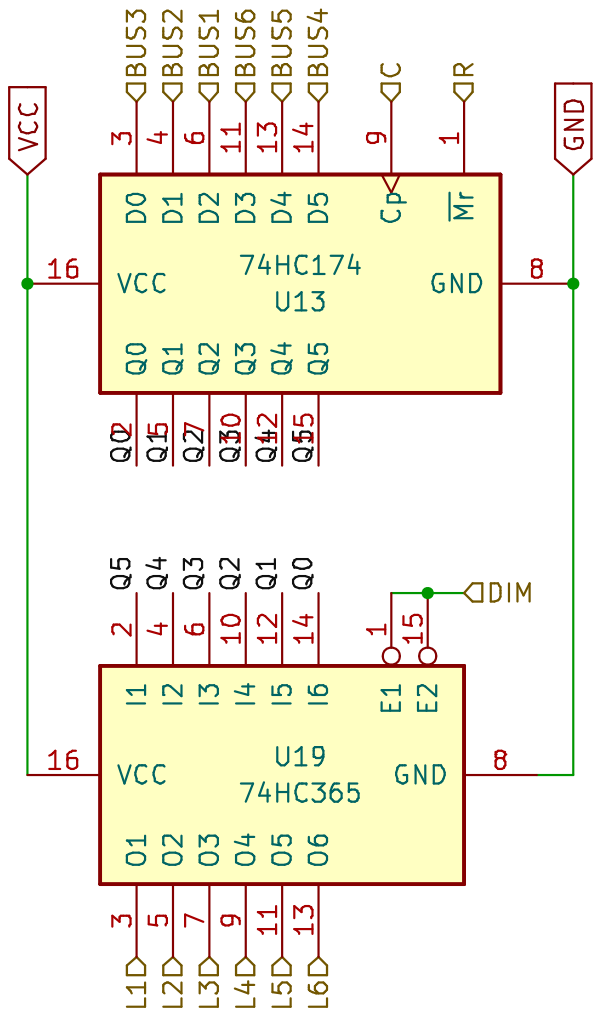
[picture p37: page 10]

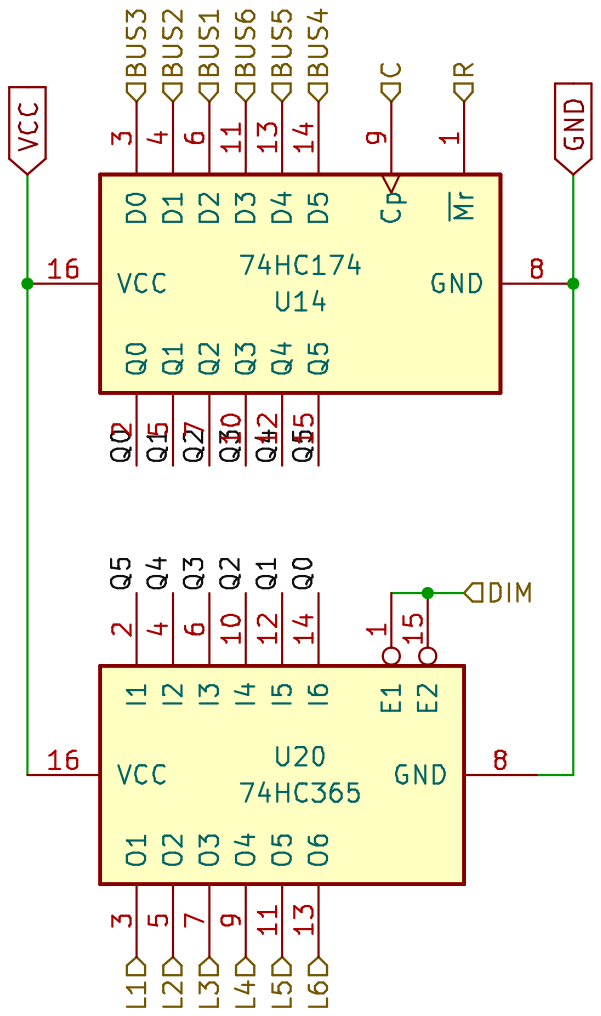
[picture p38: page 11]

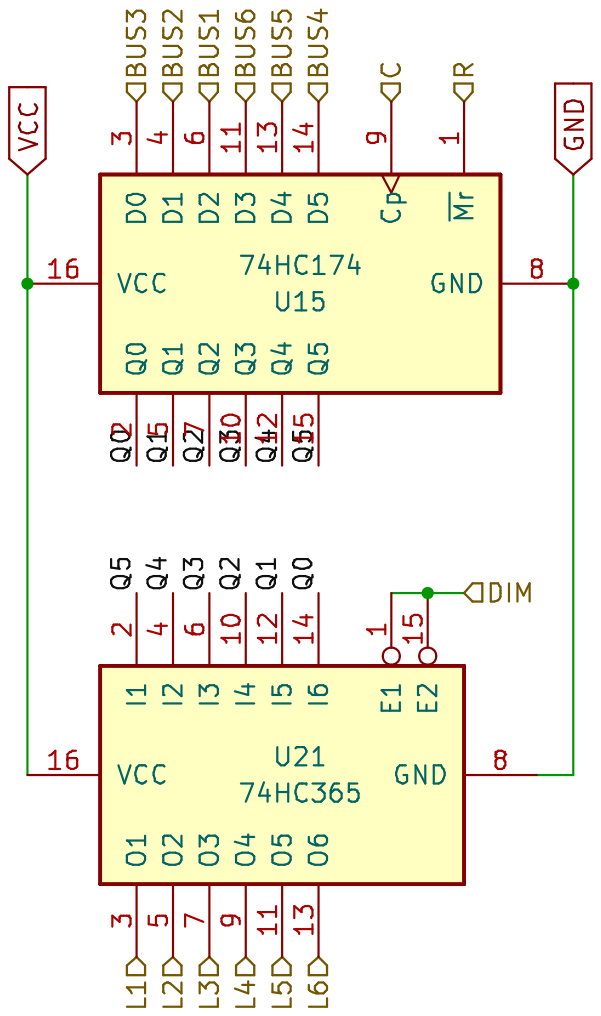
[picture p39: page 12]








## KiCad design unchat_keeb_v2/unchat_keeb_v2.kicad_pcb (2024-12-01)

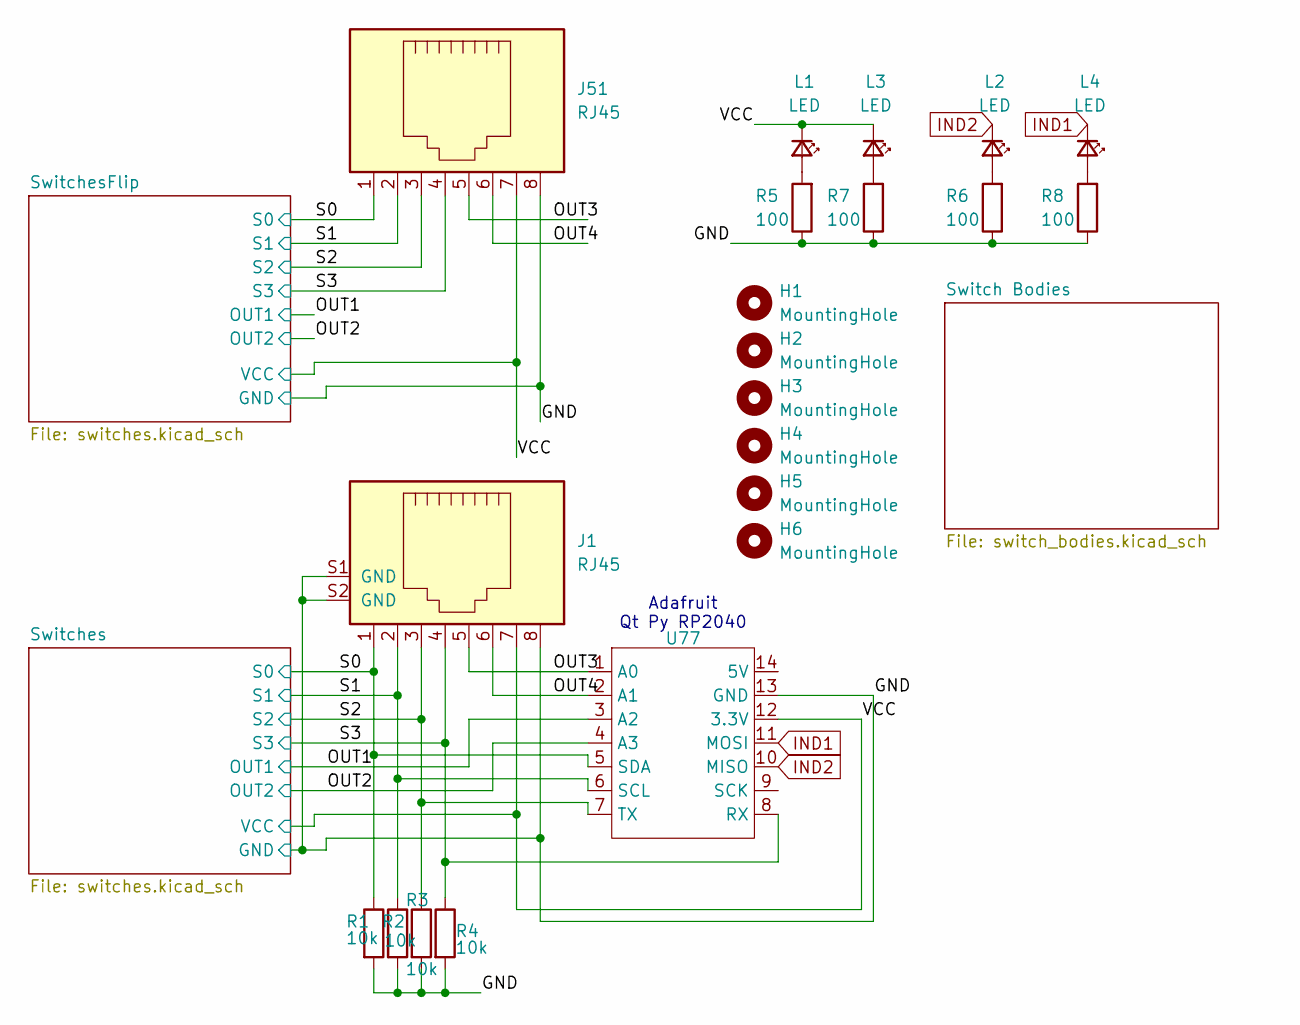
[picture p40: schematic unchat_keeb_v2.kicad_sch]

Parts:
H1, H2, H3, H4, H5, H6: MountingHole; MountingHole_2.2mm_M2
J1: RJ45; TE_2041126-1_RJ45
J51: RJ45; TE_2041126-1_RJ45_Back
L1, L2, L3, L4: LED; LED_0603_1608Metric
R1, R2, R3, R4: 10k; R_0805_2012Metric_Pad1.20x1.40mm_HandSolder
R5, R6, R7, R8: 100; R_0805_2012Metric
U77: Adafruit_QT_Py_SMD

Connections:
/GND: J1.8, J1.S1 (GND), J1.S2 (GND), J51.8, R1.2, R2.2, R3.2, R4.2, R5.1, R6.1, R7.1, R8.1, U77.13 (GND); also elsewhere on the board
/OUT1: U77.3 (A2); also elsewhere on the board
/OUT2: U77.4 (A3); also elsewhere on the board
/OUT3: J1.5, J51.5, U77.1 (A0)
/OUT4: J1.6, J51.6, U77.2 (A1)
/S0: J1.1, J51.1, R1.1, U77.5 (SDA); also elsewhere on the board
/S1: J1.2, J51.2, R2.1, U77.6 (SCL); also elsewhere on the board
/S2: J1.3, J51.3, R3.1, U77.7 (TX); also elsewhere on the board
/S3: J1.4, J51.4, R4.1, U77.8 (RX); also elsewhere on the board
/VCC: J1.7, J51.7, L1.1 (K), L3.1 (K), U77.12 (3.3V); also elsewhere on the board
IND1: L4.1 (K), U77.11 (MOSI)
IND2: L2.1 (K), U77.10 (MISO)
unnamed: L1.2 (A), R5.2
unnamed: L2.2 (A), R6.2
unnamed: L3.2 (A), R7.2
unnamed: L4.2 (A), R8.2

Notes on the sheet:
Adafruit Qt Py RP2040

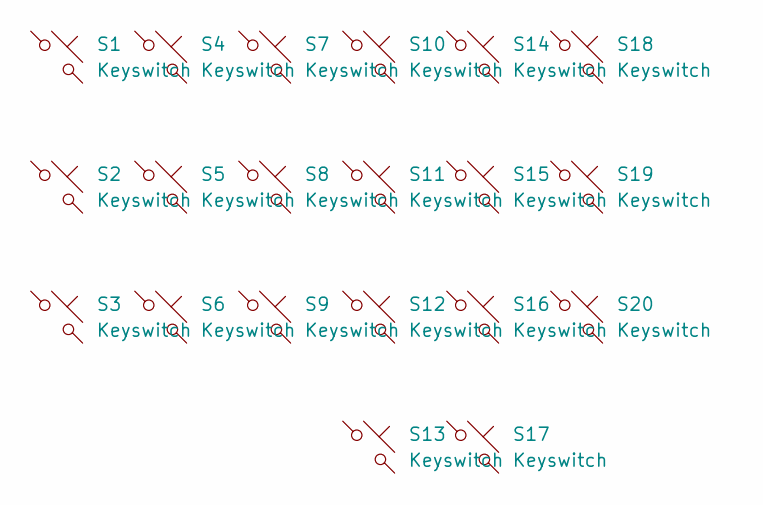
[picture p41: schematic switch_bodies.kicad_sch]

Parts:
S1, S2, S3, S4, S5, S6, S7, S8, S9, S10, S11, S12, S13, S14, S15, S16, S17, S18, S19, S20: Keyswitch; MX_HallEffect_Reversible_1.00u

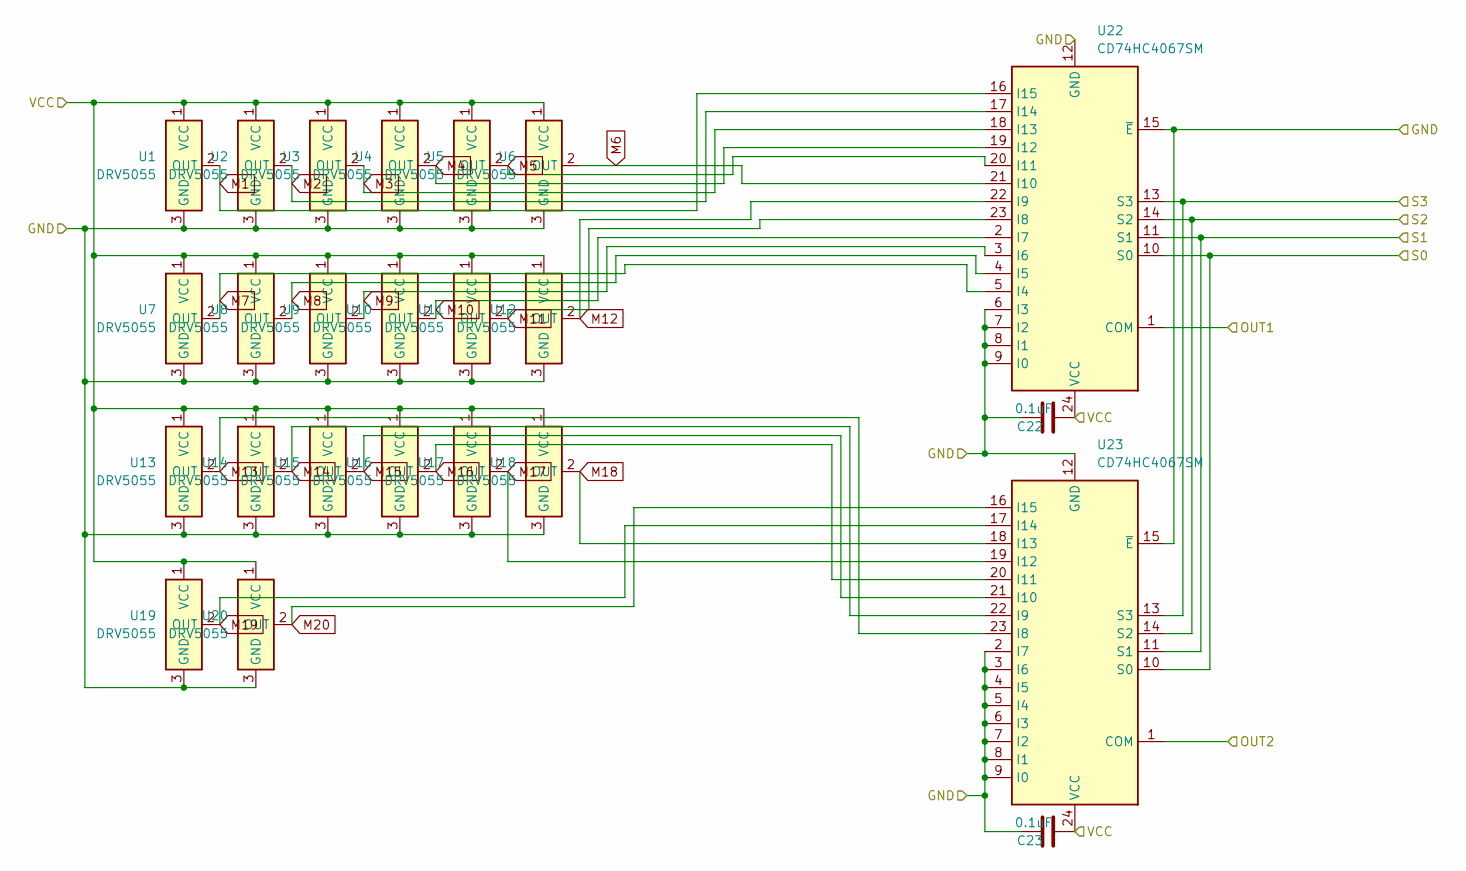
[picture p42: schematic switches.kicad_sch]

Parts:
C22, C23: 0.1uF; C_0805_2012Metric_Pad1.18x1.45mm_HandSolder
U1, U2, U3, U4, U5, U6, U7, U8, U9, U10, U11, U12, U13, U14, U15, U16, U17, U18, U19, U20: DRV5055; SOT-23
U22, U23: CD74HC4067SM; SSOP-24_5.3x8.2mm_P0.65mm

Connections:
/GND: C22.1, C23.1, U1.3 (GND), U2.3 (GND), U3.3 (GND), U4.3 (GND), U5.3 (GND), U6.3 (GND), U7.3 (GND), U8.3 (GND), U9.3 (GND), U10.3 (GND), U11.3 (GND), U12.3 (GND), U13.3 (GND), U14.3 (GND), U15.3 (GND), U16.3 (GND), U17.3 (GND), U18.3 (GND), U19.3 (GND), U20.3 (GND), U22.6 (I3), U22.7 (I2), U22.8 (I1), U22.9 (I0), U22.12 (GND), U22.15 (~E), U23.2 (I7), U23.3 (I6), U23.4 (I5), U23.5 (I4), U23.6 (I3), U23.7 (I2), U23.8 (I1), U23.9 (I0), U23.12 (GND), U23.15 (~E); also elsewhere on the board
/OUT1: U22.1 (COM); also elsewhere on the board
/OUT2: U23.1 (COM); also elsewhere on the board
/S0: U22.10 (S0), U23.10 (S0); also elsewhere on the board
/S1: U22.11 (S1), U23.11 (S1); also elsewhere on the board
/S2: U22.14 (S2), U23.14 (S2); also elsewhere on the board
/S3: U22.13 (S3), U23.13 (S3); also elsewhere on the board
/VCC: C22.2, C23.2, U1.1 (VCC), U2.1 (VCC), U3.1 (VCC), U4.1 (VCC), U5.1 (VCC), U6.1 (VCC), U7.1 (VCC), U8.1 (VCC), U9.1 (VCC), U10.1 (VCC), U11.1 (VCC), U12.1 (VCC), U13.1 (VCC), U14.1 (VCC), U15.1 (VCC), U16.1 (VCC), U17.1 (VCC), U18.1 (VCC), U19.1 (VCC), U20.1 (VCC), U22.24 (VCC), U23.24 (VCC); also elsewhere on the board
M1: U1.2 (OUT), U22.16 (I15); also elsewhere on the board
M2: U2.2 (OUT), U22.17 (I14); also elsewhere on the board
M3: U3.2 (OUT), U22.18 (I13); also elsewhere on the board
M4: U4.2 (OUT), U22.19 (I12); also elsewhere on the board
M5: U5.2 (OUT), U22.20 (I11); also elsewhere on the board
M6: U6.2 (OUT), U22.21 (I10); also elsewhere on the board
M7: U7.2 (OUT), U22.5 (I4); also elsewhere on the board
M8: U8.2 (OUT), U22.4 (I5); also elsewhere on the board
M9: U9.2 (OUT), U22.3 (I6); also elsewhere on the board
M10: U10.2 (OUT), U22.2 (I7); also elsewhere on the board
M11: U11.2 (OUT), U22.23 (I8); also elsewhere on the board
M12: U12.2 (OUT), U22.22 (I9); also elsewhere on the board
M13: U13.2 (OUT), U23.23 (I8); also elsewhere on the board
M14: U14.2 (OUT), U23.22 (I9); also elsewhere on the board
M15: U15.2 (OUT), U23.21 (I10); also elsewhere on the board
M16: U16.2 (OUT), U23.20 (I11); also elsewhere on the board
M17: U17.2 (OUT), U23.19 (I12); also elsewhere on the board
M18: U18.2 (OUT), U23.18 (I13); also elsewhere on the board
M19: U19.2 (OUT), U23.17 (I14); also elsewhere on the board
M20: U20.2 (OUT), U23.16 (I15); also elsewhere on the board

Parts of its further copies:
C72, C73: 0.1uF; C_0805_2012Metric_Pad1.18x1.45mm_HandSolder
U51, U52, U53, U54, U55, U56, U57, U58, U59, U60, U61, U62, U63, U64, U65, U66, U67, U68, U69, U70: DRV5055; SOT-23
U72, U73: CD74HC4067SM; SSOP-24_5.3x8.2mm_P0.65mm

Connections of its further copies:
/GND: C72.1, C73.1, U51.3 (GND), U52.3 (GND), U53.3 (GND), U54.3 (GND), U55.3 (GND), U56.3 (GND), U57.3 (GND), U58.3 (GND), U59.3 (GND), U60.3 (GND), U61.3 (GND), U62.3 (GND), U63.3 (GND), U64.3 (GND), U65.3 (GND), U66.3 (GND), U67.3 (GND), U68.3 (GND), U69.3 (GND), U70.3 (GND), U72.6 (I3), U72.7 (I2), U72.8 (I1), U72.9 (I0), U72.12 (GND), U72.15 (~E), U73.2 (I7), U73.3 (I6), U73.4 (I5), U73.5 (I4), U73.6 (I3), U73.7 (I2), U73.8 (I1), U73.9 (I0), U73.12 (GND), U73.15 (~E); also elsewhere on the board
/OUT1: U72.1 (COM); also elsewhere on the board
/OUT2: U73.1 (COM); also elsewhere on the board
/S0: U72.10 (S0), U73.10 (S0); also elsewhere on the board
/S1: U72.11 (S1), U73.11 (S1); also elsewhere on the board
/S2: U72.14 (S2), U73.14 (S2); also elsewhere on the board
/S3: U72.13 (S3), U73.13 (S3); also elsewhere on the board
/VCC: C72.2, C73.2, U51.1 (VCC), U52.1 (VCC), U53.1 (VCC), U54.1 (VCC), U55.1 (VCC), U56.1 (VCC), U57.1 (VCC), U58.1 (VCC), U59.1 (VCC), U60.1 (VCC), U61.1 (VCC), U62.1 (VCC), U63.1 (VCC), U64.1 (VCC), U65.1 (VCC), U66.1 (VCC), U67.1 (VCC), U68.1 (VCC), U69.1 (VCC), U70.1 (VCC), U72.24 (VCC), U73.24 (VCC); also elsewhere on the board
M1: U51.2 (OUT), U72.16 (I15); also elsewhere on the board
M2: U52.2 (OUT), U72.17 (I14); also elsewhere on the board
M3: U53.2 (OUT), U72.18 (I13); also elsewhere on the board
M4: U54.2 (OUT), U72.19 (I12); also elsewhere on the board
M5: U55.2 (OUT), U72.20 (I11); also elsewhere on the board
M6: U56.2 (OUT), U72.21 (I10); also elsewhere on the board
M7: U57.2 (OUT), U72.5 (I4); also elsewhere on the board
M8: U58.2 (OUT), U72.4 (I5); also elsewhere on the board
M9: U59.2 (OUT), U72.3 (I6); also elsewhere on the board
M10: U60.2 (OUT), U72.2 (I7); also elsewhere on the board
M11: U61.2 (OUT), U72.23 (I8); also elsewhere on the board
M12: U62.2 (OUT), U72.22 (I9); also elsewhere on the board
M13: U63.2 (OUT), U73.23 (I8); also elsewhere on the board
M14: U64.2 (OUT), U73.22 (I9); also elsewhere on the board
M15: U65.2 (OUT), U73.21 (I10); also elsewhere on the board
M16: U66.2 (OUT), U73.20 (I11); also elsewhere on the board
M17: U67.2 (OUT), U73.19 (I12); also elsewhere on the board
M18: U68.2 (OUT), U73.18 (I13); also elsewhere on the board
M19: U69.2 (OUT), U73.17 (I14); also elsewhere on the board
M20: U70.2 (OUT), U73.16 (I15); also elsewhere on the board

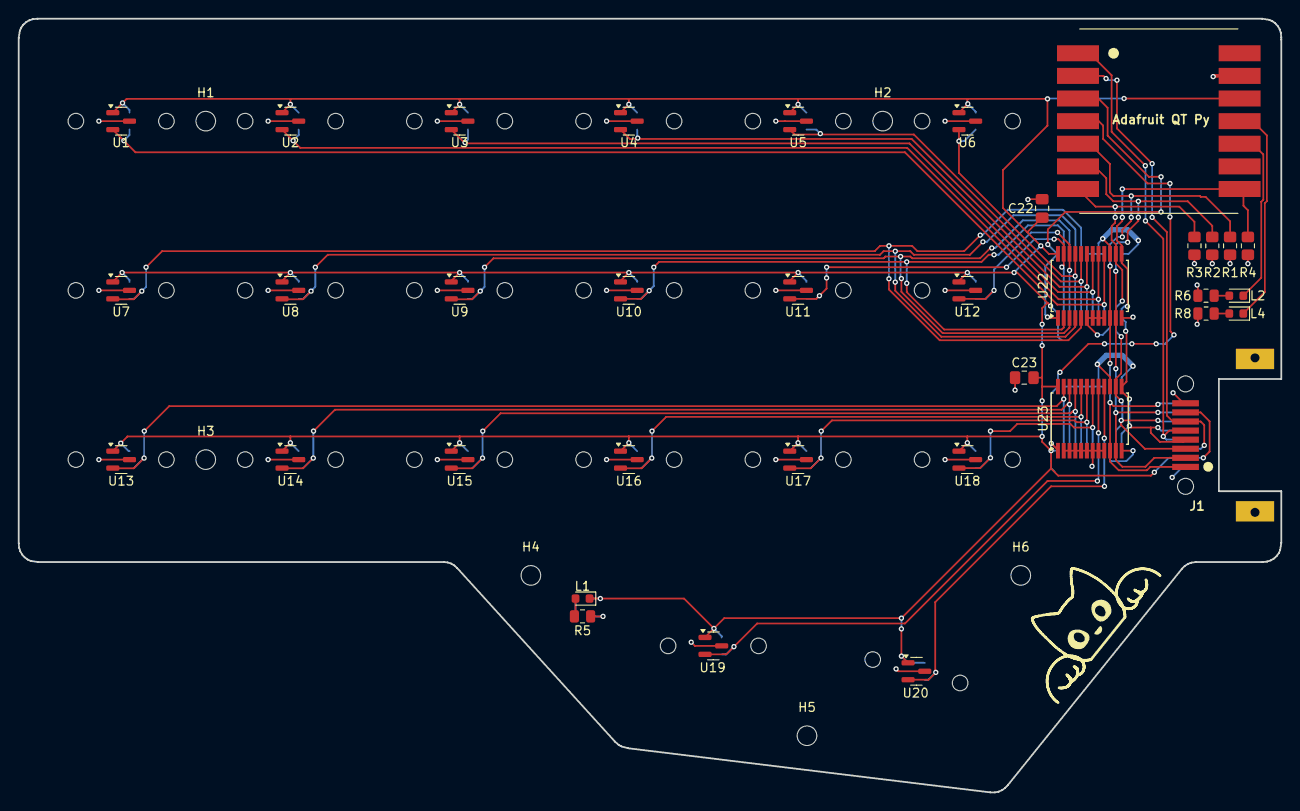
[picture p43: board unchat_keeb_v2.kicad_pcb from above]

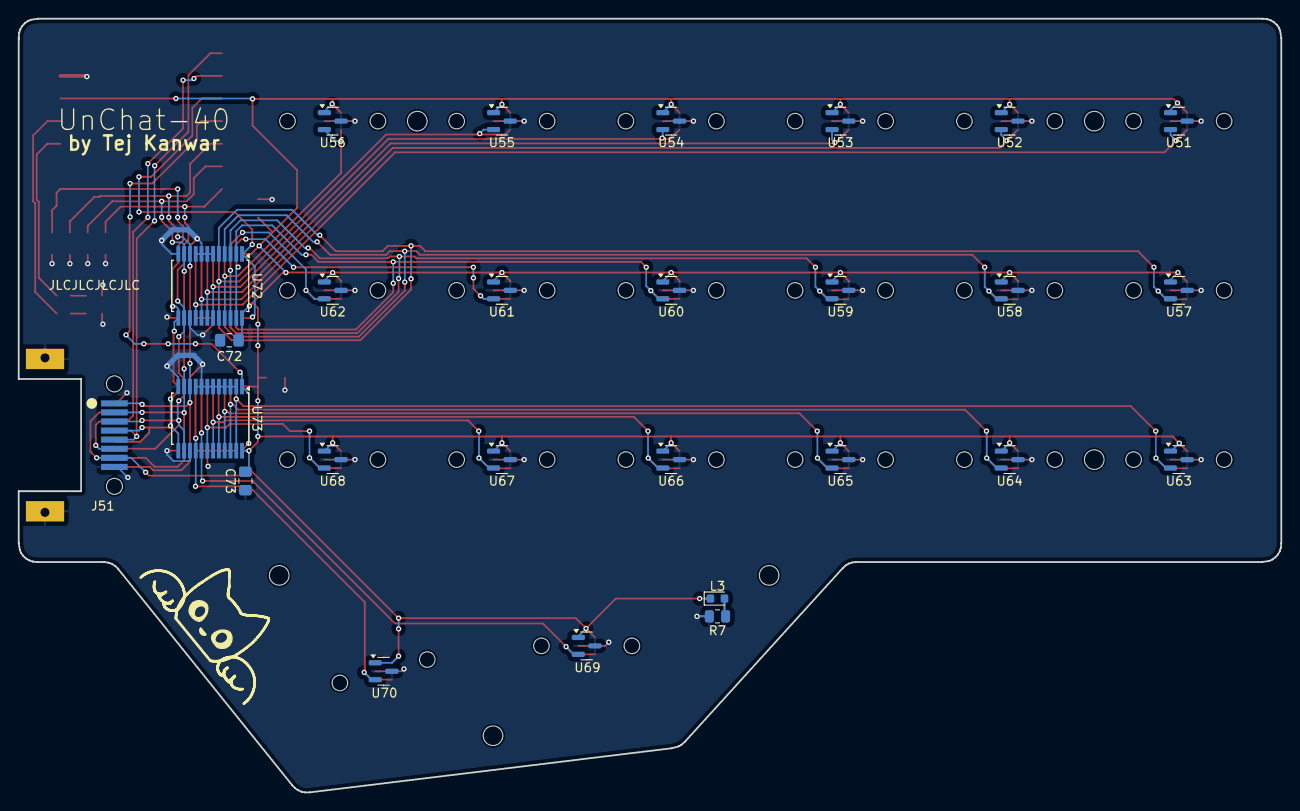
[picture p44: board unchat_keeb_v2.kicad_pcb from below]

Board: 2 copper layers, 141.8 x 86.9 mm, 89 parts (27 on the bottom side), 36 nets.

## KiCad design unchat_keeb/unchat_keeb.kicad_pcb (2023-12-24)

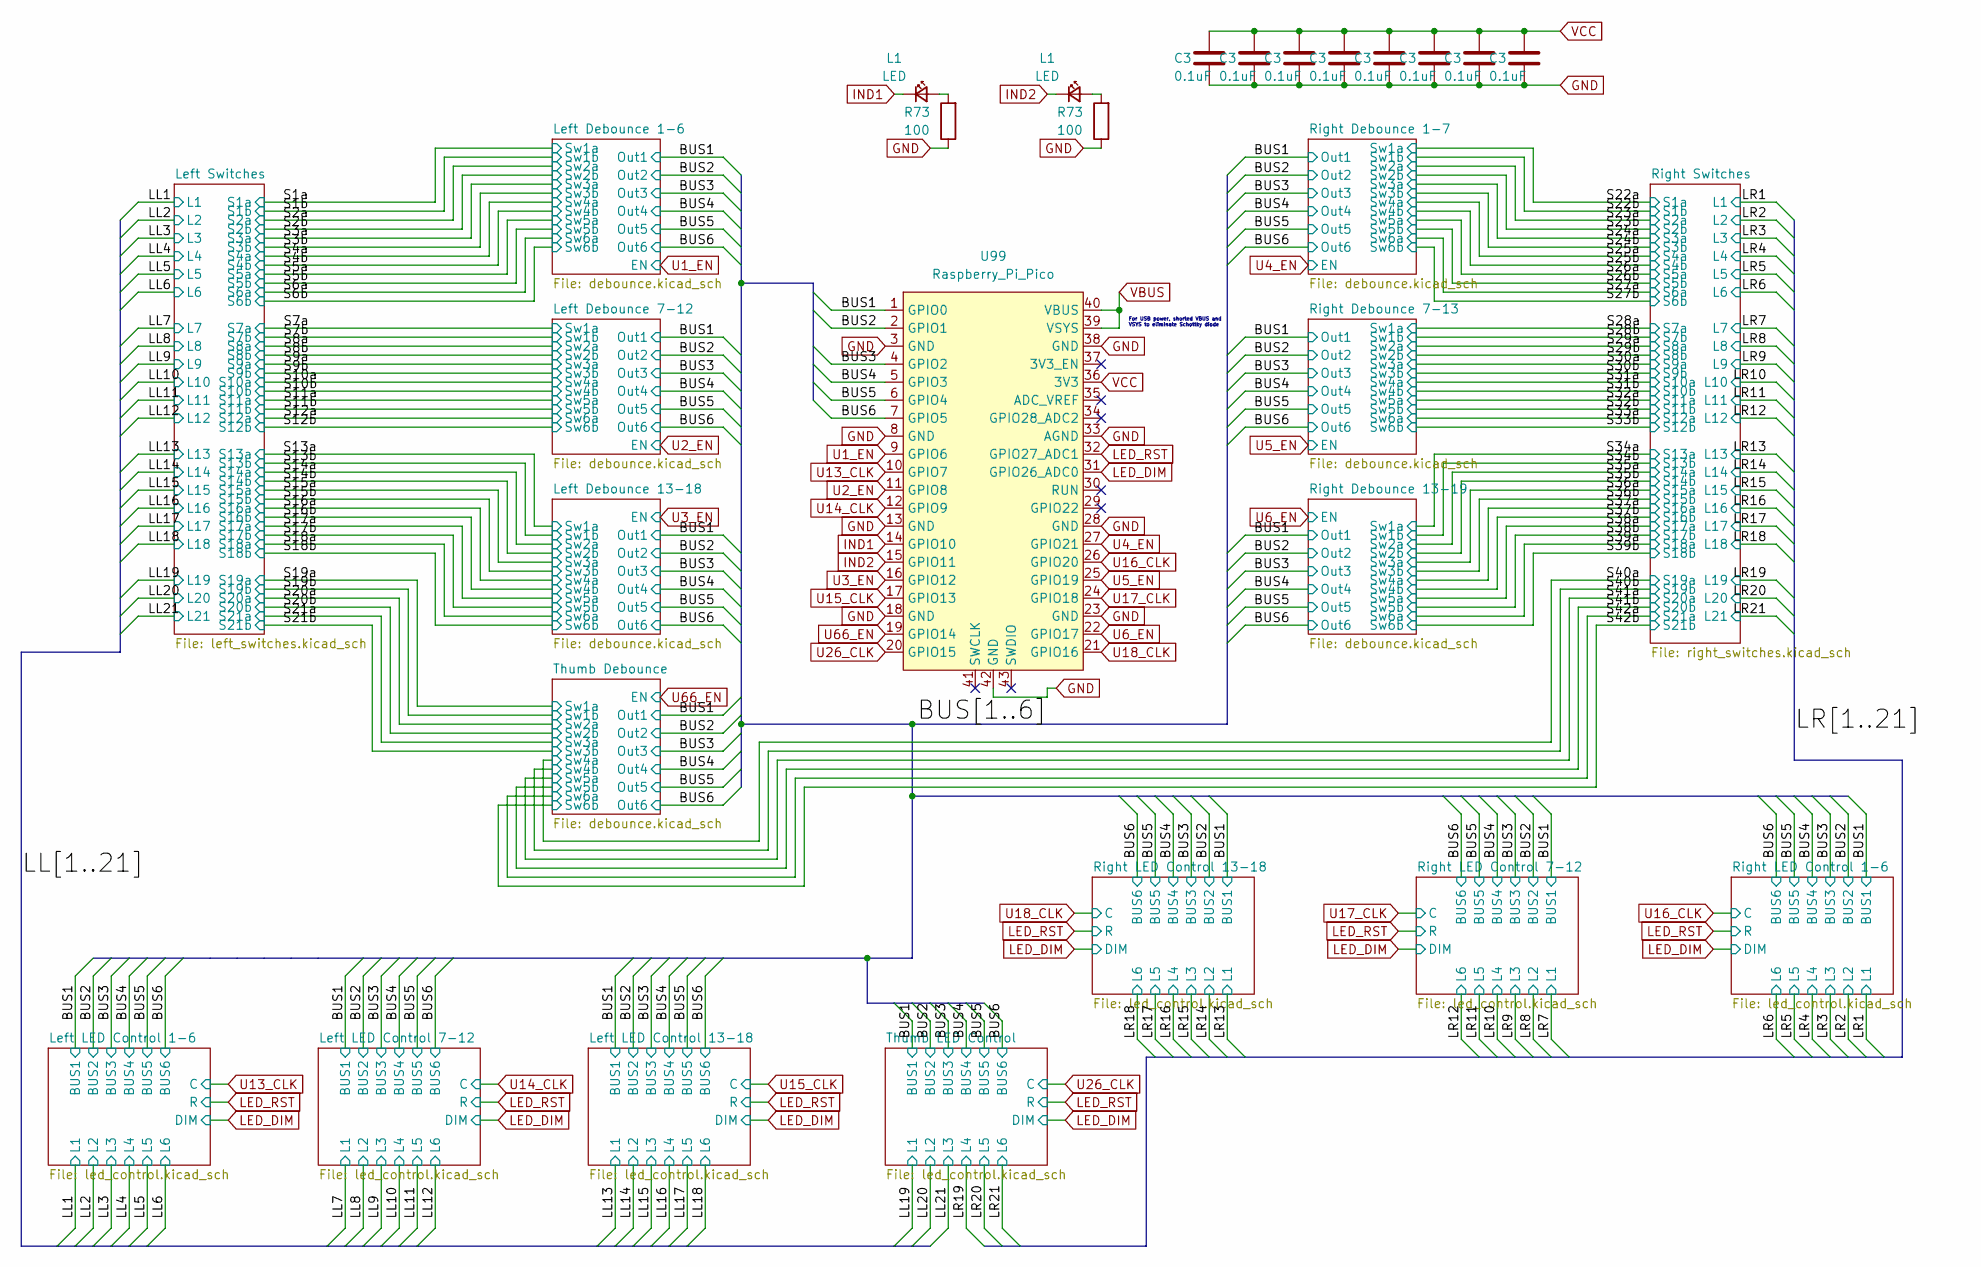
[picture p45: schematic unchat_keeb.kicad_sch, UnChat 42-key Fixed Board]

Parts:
C3: 0.1uF; C_0805_2012Metric
L1: LED; LED_0603_1608Metric
R73: 100; R_0805_2012Metric
U99: Raspberry_Pi_Pico; Raspberry_Pi_Pico_SMD

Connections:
/BUS1: U99.1 (GPIO0); also elsewhere on the board
/BUS2: U99.2 (GPIO1); also elsewhere on the board
/BUS3: U99.4 (GPIO2); also elsewhere on the board
/BUS4: U99.5 (GPIO3); also elsewhere on the board
/BUS5: U99.6 (GPIO4); also elsewhere on the board
/BUS6: U99.7 (GPIO5); also elsewhere on the board
GND: C3.2, R73.1, U99.3 (GND), U99.8 (GND), U99.13 (GND), U99.18 (GND), U99.23 (GND), U99.28 (GND), U99.33 (AGND), U99.38 (GND), U99.42 (GND); also elsewhere on the board
LED_DIM: U99.31 (GPIO26_ADC0); also elsewhere on the board
LED_RST: U99.32 (GPIO27_ADC1); also elsewhere on the board
unnamed: L1.2 (A), R73.2
U1_EN: U99.9 (GPIO6); also elsewhere on the board
U2_EN: U99.11 (GPIO8); also elsewhere on the board
U3_EN: U99.16 (GPIO12); also elsewhere on the board
U4_EN: U99.27 (GPIO21); also elsewhere on the board
U5_EN: U99.25 (GPIO19); also elsewhere on the board
U6_EN: U99.22 (GPIO17); also elsewhere on the board
U13_CLK: U99.10 (GPIO7); also elsewhere on the board
U14_CLK: U99.12 (GPIO9); also elsewhere on the board
U15_CLK: U99.17 (GPIO13); also elsewhere on the board
U16_CLK: U99.26 (GPIO20); also elsewhere on the board
U17_CLK: U99.24 (GPIO18); also elsewhere on the board
U18_CLK: U99.21 (GPIO16); also elsewhere on the board
U26_CLK: U99.20 (GPIO15); also elsewhere on the board
U66_EN: U99.19 (GPIO14); also elsewhere on the board
VBUS: U99.39 (VSYS), U99.40 (VBUS)

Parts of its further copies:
C9, C15, C21, C27, C33, C39, C43, C44, C45, C46, C47, C48, C49, C50: 0.1uF; C_0805_2012Metric
L37, L38: LED; LED_0603_1608Metric
R109, R110: 100; R_0805_2012Metric

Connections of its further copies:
/Left Debounce 7-12/Db3: C9.1; also elsewhere on the board
/Left Debounce 13-18/Db3: C15.1; also elsewhere on the board
/Right Debounce 1-7/Db3: C21.1; also elsewhere on the board
/Right Debounce 7-13/Db3: C27.1; also elsewhere on the board
/Right Debounce 13-19/Db3: C33.1; also elsewhere on the board
/Thumb Debounce/Db3: C39.1; also elsewhere on the board
GND: C9.2, C15.2, C21.2, C27.2, C33.2, C39.2, C43.2, C44.2, C45.2, C46.2, C47.2, C48.2, C49.2, C50.2, R109.1, R110.1; also elsewhere on the board
unnamed: L37.2 (A), R109.2
unnamed: L38.2 (A), R110.2

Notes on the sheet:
For USB power, shorted VBUS and VSYS to eliminate Schottky diode

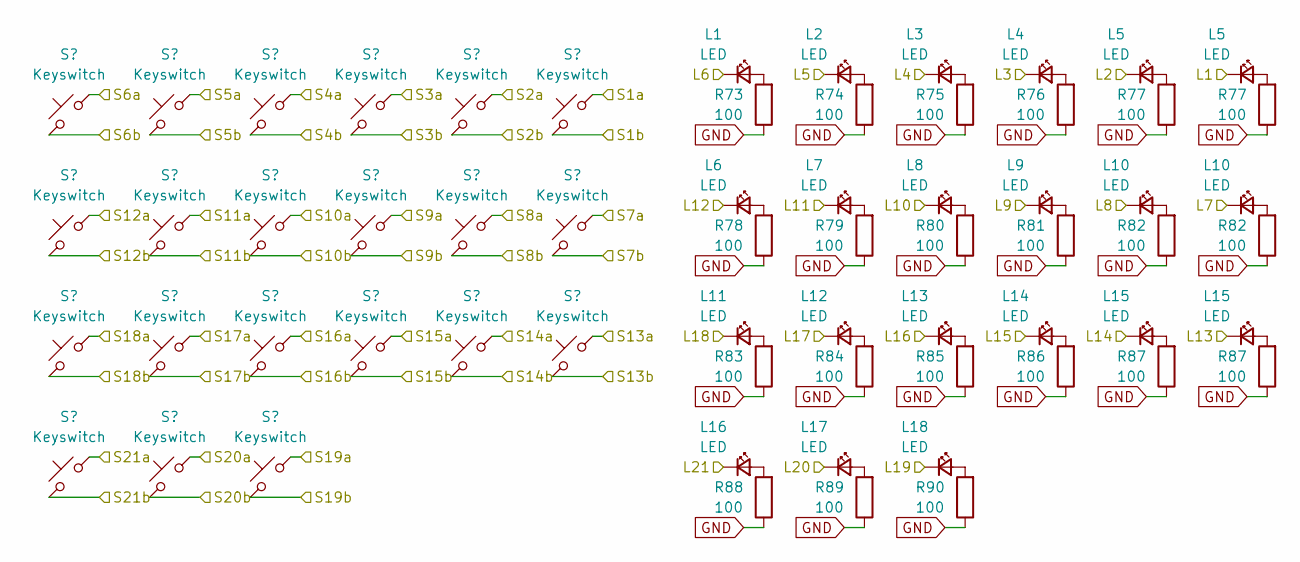
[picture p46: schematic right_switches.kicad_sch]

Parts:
L1, L2, L3, L4, L5, L6, L7, L8, L9, L10, L11, L12, L13, L14, L15, L16, L17, L18: LED; LED_0603_1608Metric
R73, R74, R75, R76, R77, R78, R79, R80, R81, R82, R83, R84, R85, R86, R87, R88, R89, R90: 100; R_0805_2012Metric
S1, S2, S3, S4, S5, S6, S7, S8, S9, S10, S11, S12, S13, S14, S15, S16: Keyswitch; Choc_V1_LED_1.00u
S17, S18: Keyswitch; Choc_V1_LED_1.50u_90deg

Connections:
/LL2: L2.1 (K); also elsewhere on the board
/LL3: L3.1 (K); also elsewhere on the board
/LL4: L4.1 (K); also elsewhere on the board
/LL5: L5.1 (K); also elsewhere on the board
/LL6: L6.1 (K); also elsewhere on the board
/LL7: L7.1 (K); also elsewhere on the board
/LL8: L8.1 (K); also elsewhere on the board
/LL9: L9.1 (K); also elsewhere on the board
/LL10: L10.1 (K); also elsewhere on the board
/LL11: L11.1 (K); also elsewhere on the board
/LL12: L12.1 (K); also elsewhere on the board
/LL13: L13.1 (K); also elsewhere on the board
/LL14: L14.1 (K); also elsewhere on the board
/LL15: L15.1 (K); also elsewhere on the board
/LL16: L16.1 (K); also elsewhere on the board
/LL17: L17.1 (K); also elsewhere on the board
/LL18: L18.1 (K); also elsewhere on the board
/S1a: S1.1; also elsewhere on the board
/S2a: S2.1; also elsewhere on the board
/S3a: S3.1; also elsewhere on the board
/S4a: S4.1; also elsewhere on the board
/S5a: S5.1; also elsewhere on the board
/S6a: S6.1; also elsewhere on the board
/S7a: S7.1; also elsewhere on the board
/S8a: S8.1; also elsewhere on the board
/S9a: S9.1; also elsewhere on the board
/S10a: S10.1; also elsewhere on the board
/S11a: S11.1; also elsewhere on the board
/S12a: S12.1; also elsewhere on the board
/S13a: S13.1; also elsewhere on the board
/S14a: S14.1; also elsewhere on the board
/S15a: S15.1; also elsewhere on the board
/S16a: S16.1; also elsewhere on the board
/S17a: S17.1; also elsewhere on the board
/S18a: S18.1; also elsewhere on the board
GND: R73.1, R74.1, R75.1, R76.1, R77.1, R78.1, R79.1, R80.1, R81.1, R82.1, R83.1, R84.1, R85.1, R86.1, R87.1, R88.1, R89.1, R90.1, S1.2, S2.2, S3.2, S4.2, S5.2, S6.2, S7.2, S8.2, S9.2, S10.2, S11.2, S12.2, S13.2, S14.2, S15.2, S16.2, S17.2, S18.2; also elsewhere on the board
unnamed: L1.2 (A), R73.2
unnamed: L2.2 (A), R74.2
unnamed: L3.2 (A), R75.2
unnamed: L4.2 (A), R76.2
unnamed: L5.2 (A), R77.2
unnamed: L6.2 (A), R78.2
unnamed: L7.2 (A), R79.2
unnamed: L8.2 (A), R80.2
unnamed: L9.2 (A), R81.2
unnamed: L10.2 (A), R82.2
unnamed: L11.2 (A), R83.2
unnamed: L12.2 (A), R84.2
unnamed: L13.2 (A), R85.2
unnamed: L14.2 (A), R86.2
unnamed: L15.2 (A), R87.2
unnamed: L16.2 (A), R88.2
unnamed: L17.2 (A), R89.2
unnamed: L18.2 (A), R90.2

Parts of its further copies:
L22, L23, L24, L25, L26, L27, L28, L29, L30, L31, L32, L33, L34, L35, L36, L39, L40, L41, L42, L43, L44: LED; LED_0603_1608Metric
R91, R92, R93, R94, R95, R96, R97, R98, R99, R100, R101, R102, R103, R104, R105, R106, R107, R108, R114, R115, R116: 100; R_0805_2012Metric
S22, S23, S24, S25, S26, S27, S28, S29, S30, S31, S32, S33, S34, S35, S36, S37, S38, S39, S40: Keyswitch; Choc_V1_LED_1.00u
S41, S42: Keyswitch; Choc_V1_LED_1.50u_90deg

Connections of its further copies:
/LR1: L22.1 (K); also elsewhere on the board
/LR2: L23.1 (K); also elsewhere on the board
/LR3: L24.1 (K); also elsewhere on the board
/LR4: L25.1 (K); also elsewhere on the board
/LR5: L26.1 (K); also elsewhere on the board
/LR6: L27.1 (K); also elsewhere on the board
/LR7: L28.1 (K); also elsewhere on the board
/LR8: L29.1 (K); also elsewhere on the board
/LR9: L30.1 (K); also elsewhere on the board
/LR10: L31.1 (K); also elsewhere on the board
/LR11: L32.1 (K); also elsewhere on the board
/LR12: L33.1 (K); also elsewhere on the board
/LR13: L34.1 (K); also elsewhere on the board
/LR14: L35.1 (K); also elsewhere on the board
/LR15: L36.1 (K); also elsewhere on the board
/LR16: L39.1 (K); also elsewhere on the board
/LR17: L40.1 (K); also elsewhere on the board
/LR18: L41.1 (K); also elsewhere on the board
/LR19: L42.1 (K); also elsewhere on the board
/LR20: L43.1 (K); also elsewhere on the board
/LR21: L44.1 (K); also elsewhere on the board
/S22a: S22.1; also elsewhere on the board
/S23a: S23.1; also elsewhere on the board
/S24a: S24.1; also elsewhere on the board
/S25a: S25.1; also elsewhere on the board
/S26a: S26.1; also elsewhere on the board
/S27a: S27.1; also elsewhere on the board
/S28a: S28.1; also elsewhere on the board
/S29a: S29.1; also elsewhere on the board
/S30a: S30.1; also elsewhere on the board
/S31a: S31.1; also elsewhere on the board
/S32a: S32.1; also elsewhere on the board
/S33a: S33.1; also elsewhere on the board
/S34a: S34.1; also elsewhere on the board
/S35a: S35.1; also elsewhere on the board
/S36a: S36.1; also elsewhere on the board
/S37a: S37.1; also elsewhere on the board
/S38a: S38.1; also elsewhere on the board
/S39a: S39.1; also elsewhere on the board
/S40a: S40.1; also elsewhere on the board
/S41a: S41.1; also elsewhere on the board
/S42a: S42.1; also elsewhere on the board
GND: R91.1, R92.1, R93.1, R94.1, R95.1, R96.1, R97.1, R98.1, R99.1, R100.1, R101.1, R102.1, R103.1, R104.1, R105.1, R106.1, R107.1, R108.1, R114.1, R115.1, R116.1, S22.2, S23.2, S24.2, S25.2, S26.2, S27.2, S28.2, S29.2, S30.2, S31.2, S32.2, S33.2, S34.2, S35.2, S36.2, S37.2, S38.2, S39.2, S40.2, S41.2, S42.2; also elsewhere on the board
unnamed: L22.2 (A), R91.2
unnamed: L23.2 (A), R92.2
unnamed: L24.2 (A), R93.2
unnamed: L25.2 (A), R94.2
unnamed: L26.2 (A), R95.2
unnamed: L27.2 (A), R96.2
unnamed: L28.2 (A), R97.2
unnamed: L29.2 (A), R98.2
unnamed: L30.2 (A), R99.2
unnamed: L31.2 (A), R100.2
unnamed: L32.2 (A), R101.2
unnamed: L33.2 (A), R102.2
unnamed: L34.2 (A), R103.2
unnamed: L35.2 (A), R104.2
unnamed: L36.2 (A), R105.2
unnamed: L39.2 (A), R106.2
unnamed: L40.2 (A), R107.2
unnamed: L41.2 (A), R108.2
unnamed: L42.2 (A), R114.2
unnamed: L43.2 (A), R115.2
unnamed: L44.2 (A), R116.2

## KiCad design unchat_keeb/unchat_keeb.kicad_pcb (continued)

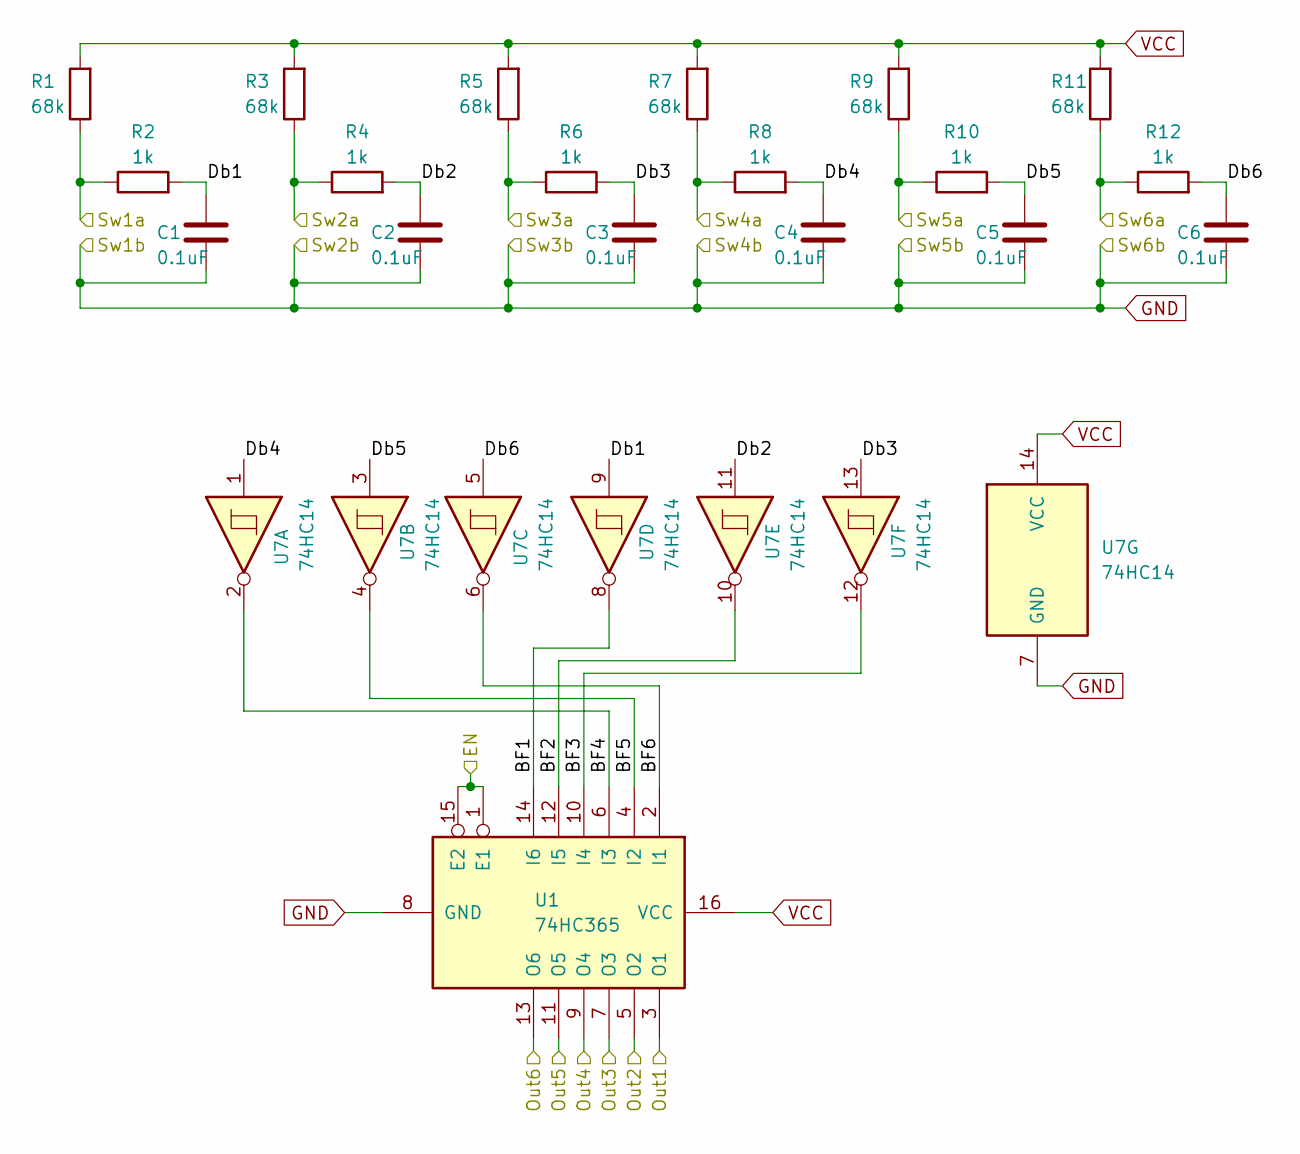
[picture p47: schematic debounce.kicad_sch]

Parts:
C1, C2, C3, C4, C5, C6: 0.1uF; C_0805_2012Metric
R1, R3, R5, R7, R9, R11: 68k; R_0805_2012Metric
R2, R4, R6, R8, R10, R12: 1k; R_0805_2012Metric
U1: 74HC365; TSSOP-16_4.4x5mm_P0.65mm
U7: 74HC14; TSSOP-14_4.4x5mm_P0.65mm

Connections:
/BUS1: U1.3 (O1); also elsewhere on the board
/BUS2: U1.5 (O2); also elsewhere on the board
/BUS3: U1.7 (O3); also elsewhere on the board
/BUS4: U1.9 (O4); also elsewhere on the board
/BUS5: U1.11 (O5); also elsewhere on the board
/BUS6: U1.13 (O6); also elsewhere on the board
/Left Debounce 1-6/BF1: U1.14 (I6), U7.8
/Left Debounce 1-6/BF2: U1.12 (I5), U7.10
/Left Debounce 1-6/BF3: U1.10 (I4), U7.12
/Left Debounce 1-6/BF4: U1.6 (I3), U7.2
/Left Debounce 1-6/BF5: U1.4 (I2), U7.4
/Left Debounce 1-6/BF6: U1.2 (I1), U7.6
/Left Debounce 1-6/Db1: C1.1, R2.2, U7.9
/Left Debounce 1-6/Db2: C2.1, R4.2, U7.11
/Left Debounce 1-6/Db4: C4.1, R8.2, U7.1
/Left Debounce 1-6/Db5: C5.1, R10.2, U7.3
/Left Debounce 1-6/Db6: C6.1, R12.2, U7.5
/S1a: R1.1, R2.1; also elsewhere on the board
/S2a: R3.1, R4.1; also elsewhere on the board
/S3a: R5.1, R6.1; also elsewhere on the board
/S4a: R7.1, R8.1; also elsewhere on the board
/S5a: R9.1, R10.1; also elsewhere on the board
/S6a: R11.1, R12.1; also elsewhere on the board
GND: C1.2, C2.2, C3.2, C4.2, C5.2, C6.2, U1.8 (GND), U7.7 (GND); also elsewhere on the board
U1_EN: U1.1 (E1), U1.15 (E2); also elsewhere on the board

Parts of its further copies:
C7, C8, C9, C10, C11, C12, C13, C14, C15, C16, C17, C18, C19, C20, C21, C22, C23, C24, C25, C26, C27, C28, C29, C30, C31, C32, C33, C34, C35, C36, C37, C38, C39, C40, C41, C42: 0.1uF; C_0805_2012Metric
R13, R15, R17, R19, R21, R23, R25, R27, R29, R31, R33, R35, R37, R39, R41, R43, R45, R47, R49, R51, R53, R55, R57, R59, R61, R63, R65, R67, R69, R71, R117, R118, R119, R120, R121, R122: 68k; R_0805_2012Metric
R14, R16, R18, R20, R22, R24, R26, R28, R30, R32, R34, R36, R38, R40, R42, R44, R46, R48, R50, R52, R54, R56, R58, R60, R62, R64, R66, R68, R70, R72, R123, R124, R125, R126, R127, R128: 1k; R_0805_2012Metric
U2, U3, U4, U5, U6, U66: 74HC365; TSSOP-16_4.4x5mm_P0.65mm
U8, U9, U10, U11, U12, U25: 74HC14; TSSOP-14_4.4x5mm_P0.65mm

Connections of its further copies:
/BUS1: U2.3 (O1), U3.3 (O1), U4.3 (O1), U5.3 (O1), U6.3 (O1), U66.3 (O1); also elsewhere on the board
/BUS2: U2.5 (O2), U3.5 (O2), U4.5 (O2), U5.5 (O2), U6.5 (O2), U66.5 (O2); also elsewhere on the board
/BUS3: U2.7 (O3), U3.7 (O3), U4.7 (O3), U5.7 (O3), U6.7 (O3), U66.7 (O3); also elsewhere on the board
/BUS4: U2.9 (O4), U3.9 (O4), U4.9 (O4), U5.9 (O4), U6.9 (O4), U66.9 (O4); also elsewhere on the board
/BUS5: U2.11 (O5), U3.11 (O5), U4.11 (O5), U5.11 (O5), U6.11 (O5), U66.11 (O5); also elsewhere on the board
/BUS6: U2.13 (O6), U3.13 (O6), U4.13 (O6), U5.13 (O6), U6.13 (O6), U66.13 (O6); also elsewhere on the board
/Left Debounce 7-12/BF1: U2.14 (I6), U8.8
/Left Debounce 7-12/BF2: U2.12 (I5), U8.10
/Left Debounce 7-12/BF3: U2.10 (I4), U8.12
/Left Debounce 7-12/BF4: U2.6 (I3), U8.2
/Left Debounce 7-12/BF5: U2.4 (I2), U8.4
/Left Debounce 7-12/BF6: U2.2 (I1), U8.6
/Left Debounce 7-12/Db1: C7.1, R14.2, U8.9
/Left Debounce 7-12/Db2: C8.1, R16.2, U8.11
/Left Debounce 7-12/Db3: C9.1, R18.2, U8.13
/Left Debounce 7-12/Db4: C10.1, R20.2, U8.1
/Left Debounce 7-12/Db5: C11.1, R22.2, U8.3
/Left Debounce 7-12/Db6: C12.1, R24.2, U8.5
/Left Debounce 13-18/BF1: U3.14 (I6), U9.8
/Left Debounce 13-18/BF2: U3.12 (I5), U9.10
/Left Debounce 13-18/BF3: U3.10 (I4), U9.12
/Left Debounce 13-18/BF4: U3.6 (I3), U9.2
/Left Debounce 13-18/BF5: U3.4 (I2), U9.4
/Left Debounce 13-18/BF6: U3.2 (I1), U9.6
/Left Debounce 13-18/Db1: C13.1, R26.2, U9.9
/Left Debounce 13-18/Db2: C14.1, R28.2, U9.11
/Left Debounce 13-18/Db3: C15.1, R30.2, U9.13
/Left Debounce 13-18/Db4: C16.1, R32.2, U9.1
/Left Debounce 13-18/Db5: C17.1, R34.2, U9.3
/Left Debounce 13-18/Db6: C18.1, R36.2, U9.5
/Right Debounce 1-7/BF1: U4.14 (I6), U10.8
/Right Debounce 1-7/BF2: U4.12 (I5), U10.10
/Right Debounce 1-7/BF3: U4.10 (I4), U10.12
/Right Debounce 1-7/BF4: U4.6 (I3), U10.2
/Right Debounce 1-7/BF5: U4.4 (I2), U10.4
/Right Debounce 1-7/BF6: U4.2 (I1), U10.6
/Right Debounce 1-7/Db1: C19.1, R38.2, U10.9
/Right Debounce 1-7/Db2: C20.1, R40.2, U10.11
/Right Debounce 1-7/Db3: C21.1, R42.2, U10.13
/Right Debounce 1-7/Db4: C22.1, R44.2, U10.1
/Right Debounce 1-7/Db5: C23.1, R46.2, U10.3
/Right Debounce 1-7/Db6: C24.1, R48.2, U10.5
/Right Debounce 7-13/BF1: U5.14 (I6), U11.8
/Right Debounce 7-13/BF2: U5.12 (I5), U11.10
/Right Debounce 7-13/BF3: U5.10 (I4), U11.12
/Right Debounce 7-13/BF4: U5.6 (I3), U11.2
/Right Debounce 7-13/BF5: U5.4 (I2), U11.4
/Right Debounce 7-13/BF6: U5.2 (I1), U11.6
/Right Debounce 7-13/Db1: C25.1, R50.2, U11.9
/Right Debounce 7-13/Db2: C26.1, R52.2, U11.11
/Right Debounce 7-13/Db3: C27.1, R54.2, U11.13
/Right Debounce 7-13/Db4: C28.1, R56.2, U11.1
/Right Debounce 7-13/Db5: C29.1, R58.2, U11.3
/Right Debounce 7-13/Db6: C30.1, R60.2, U11.5
/Right Debounce 13-19/BF1: U6.14 (I6), U12.8
/Right Debounce 13-19/BF2: U6.12 (I5), U12.10
/Right Debounce 13-19/BF3: U6.10 (I4), U12.12
/Right Debounce 13-19/BF4: U6.6 (I3), U12.2
/Right Debounce 13-19/BF5: U6.4 (I2), U12.4
/Right Debounce 13-19/BF6: U6.2 (I1), U12.6
/Right Debounce 13-19/Db1: C31.1, R62.2, U12.9
/Right Debounce 13-19/Db2: C32.1, R64.2, U12.11
/Right Debounce 13-19/Db3: C33.1, R66.2, U12.13
/Right Debounce 13-19/Db4: C34.1, R68.2, U12.1
/Right Debounce 13-19/Db5: C35.1, R70.2, U12.3
/Right Debounce 13-19/Db6: C36.1, R72.2, U12.5
/S7a: R13.1, R14.1; also elsewhere on the board
/S8a: R15.1, R16.1; also elsewhere on the board
/S9a: R17.1, R18.1; also elsewhere on the board
/S10a: R19.1, R20.1; also elsewhere on the board
/S11a: R21.1, R22.1; also elsewhere on the board
/S12a: R23.1, R24.1; also elsewhere on the board
/S13a: R25.1, R26.1; also elsewhere on the board
/S14a: R27.1, R28.1; also elsewhere on the board
/S15a: R29.1, R30.1; also elsewhere on the board
/S16a: R31.1, R32.1; also elsewhere on the board
/S17a: R33.1, R34.1; also elsewhere on the board
/S18a: R35.1, R36.1; also elsewhere on the board
/S19a: R117.1, R123.1; also elsewhere on the board
/S20a: R118.1, R124.1; also elsewhere on the board
/S21a: R119.1, R125.1; also elsewhere on the board
/S22a: R37.1, R38.1; also elsewhere on the board
/S23a: R39.1, R40.1; also elsewhere on the board
/S24a: R41.1, R42.1; also elsewhere on the board
/S25a: R43.1, R44.1; also elsewhere on the board
/S26a: R45.1, R46.1; also elsewhere on the board
/S27a: R47.1, R48.1; also elsewhere on the board
/S28a: R49.1, R50.1; also elsewhere on the board
/S29a: R51.1, R52.1; also elsewhere on the board
/S30a: R53.1, R54.1; also elsewhere on the board
/S31a: R55.1, R56.1; also elsewhere on the board
/S32a: R57.1, R58.1; also elsewhere on the board
/S33a: R59.1, R60.1; also elsewhere on the board
/S34a: R61.1, R62.1; also elsewhere on the board
/S35a: R63.1, R64.1; also elsewhere on the board
/S36a: R65.1, R66.1; also elsewhere on the board
/S37a: R67.1, R68.1; also elsewhere on the board
/S38a: R69.1, R70.1; also elsewhere on the board
/S39a: R71.1, R72.1; also elsewhere on the board
/S40a: R120.1, R126.1; also elsewhere on the board
/S41a: R121.1, R127.1; also elsewhere on the board
/S42a: R122.1, R128.1; also elsewhere on the board
/Thumb Debounce/BF1: U25.8, U66.14 (I6)
/Thumb Debounce/BF2: U25.10, U66.12 (I5)
/Thumb Debounce/BF3: U25.12, U66.10 (I4)
/Thumb Debounce/BF4: U25.2, U66.6 (I3)
/Thumb Debounce/BF5: U25.4, U66.4 (I2)
/Thumb Debounce/BF6: U25.6, U66.2 (I1)
/Thumb Debounce/Db1: C37.1, R123.2, U25.9
/Thumb Debounce/Db2: C38.1, R124.2, U25.11
/Thumb Debounce/Db3: C39.1, R125.2, U25.13
/Thumb Debounce/Db4: C40.1, R126.2, U25.1
/Thumb Debounce/Db5: C41.1, R127.2, U25.3
/Thumb Debounce/Db6: C42.1, R128.2, U25.5
GND: C7.2, C8.2, C9.2, C10.2, C11.2, C12.2, C13.2, C14.2, C15.2, C16.2, C17.2, C18.2, C19.2, C20.2, C21.2, C22.2, C23.2, C24.2, C25.2, C26.2, C27.2, C28.2, C29.2, C30.2, C31.2, C32.2, C33.2, C34.2, C35.2, C36.2, C37.2, C38.2, C39.2, C40.2, C41.2, C42.2, U2.8 (GND), U3.8 (GND), U4.8 (GND), U5.8 (GND), U6.8 (GND), U8.7 (GND), U9.7 (GND), U10.7 (GND), U11.7 (GND), U12.7 (GND), U25.7 (GND), U66.8 (GND); also elsewhere on the board
U2_EN: U2.1 (E1), U2.15 (E2); also elsewhere on the board
U3_EN: U3.1 (E1), U3.15 (E2); also elsewhere on the board
U4_EN: U4.1 (E1), U4.15 (E2); also elsewhere on the board
U5_EN: U5.1 (E1), U5.15 (E2); also elsewhere on the board
U6_EN: U6.1 (E1), U6.15 (E2); also elsewhere on the board
U66_EN: U66.1 (E1), U66.15 (E2); also elsewhere on the board

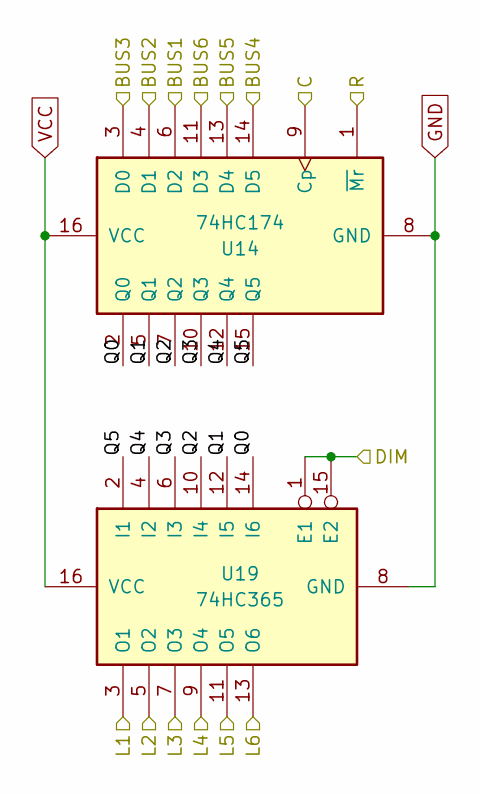
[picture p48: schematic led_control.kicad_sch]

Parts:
U14: 74HC174; TSSOP-16_4.4x5mm_P0.65mm
U19: 74HC365; TSSOP-16_4.4x5mm_P0.65mm

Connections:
/BUS1: U14.6 (D2); also elsewhere on the board
/BUS2: U14.4 (D1); also elsewhere on the board
/BUS3: U14.3 (D0); also elsewhere on the board
/BUS4: U14.14 (D5); also elsewhere on the board
/BUS5: U14.13 (D4); also elsewhere on the board
/BUS6: U14.11 (D3); also elsewhere on the board
/LL2: U19.5 (O2); also elsewhere on the board
/LL3: U19.7 (O3); also elsewhere on the board
/LL4: U19.9 (O4); also elsewhere on the board
/LL5: U19.11 (O5); also elsewhere on the board
/LL6: U19.13 (O6); also elsewhere on the board
GND: U14.8 (GND), U19.8 (GND); also elsewhere on the board
LED_DIM: U19.1 (E1), U19.15 (E2); also elsewhere on the board
LED_RST: U14.1 (~Mr); also elsewhere on the board
U14_CLK: U14.9 (Cp); also elsewhere on the board

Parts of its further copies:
U13, U15, U16, U17, U18, U26: 74HC174; TSSOP-16_4.4x5mm_P0.65mm
U20, U21, U22, U23, U24, U27: 74HC365; TSSOP-16_4.4x5mm_P0.65mm

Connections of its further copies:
/BUS1: U13.6 (D2), U15.6 (D2), U16.6 (D2), U17.6 (D2), U18.6 (D2), U26.6 (D2); also elsewhere on the board
/BUS2: U13.4 (D1), U15.4 (D1), U16.4 (D1), U17.4 (D1), U18.4 (D1), U26.4 (D1); also elsewhere on the board
/BUS3: U13.3 (D0), U15.3 (D0), U16.3 (D0), U17.3 (D0), U18.3 (D0), U26.3 (D0); also elsewhere on the board
/BUS4: U13.14 (D5), U15.14 (D5), U16.14 (D5), U17.14 (D5), U18.14 (D5), U26.14 (D5); also elsewhere on the board
/BUS5: U13.13 (D4), U15.13 (D4), U16.13 (D4), U17.13 (D4), U18.13 (D4), U26.13 (D4); also elsewhere on the board
/BUS6: U13.11 (D3), U15.11 (D3), U16.11 (D3), U17.11 (D3), U18.11 (D3), U26.11 (D3); also elsewhere on the board
/LL7: U20.3 (O1); also elsewhere on the board
/LL8: U20.5 (O2); also elsewhere on the board
/LL9: U20.7 (O3); also elsewhere on the board
/LL10: U20.9 (O4); also elsewhere on the board
/LL11: U20.11 (O5); also elsewhere on the board
/LL12: U20.13 (O6); also elsewhere on the board
/LL13: U21.3 (O1); also elsewhere on the board
/LL14: U21.5 (O2); also elsewhere on the board
/LL15: U21.7 (O3); also elsewhere on the board
/LL16: U21.9 (O4); also elsewhere on the board
/LL17: U21.11 (O5); also elsewhere on the board
/LL18: U21.13 (O6); also elsewhere on the board
/LL19: U27.3 (O1); also elsewhere on the board
/LL20: U27.5 (O2); also elsewhere on the board
/LL21: U27.7 (O3); also elsewhere on the board
/LR1: U22.3 (O1); also elsewhere on the board
/LR2: U22.5 (O2); also elsewhere on the board
/LR3: U22.7 (O3); also elsewhere on the board
/LR4: U22.9 (O4); also elsewhere on the board
/LR5: U22.11 (O5); also elsewhere on the board
/LR6: U22.13 (O6); also elsewhere on the board
/LR7: U23.3 (O1); also elsewhere on the board
/LR8: U23.5 (O2); also elsewhere on the board
/LR9: U23.7 (O3); also elsewhere on the board
/LR10: U23.9 (O4); also elsewhere on the board
/LR11: U23.11 (O5); also elsewhere on the board
/LR12: U23.13 (O6); also elsewhere on the board
/LR13: U24.3 (O1); also elsewhere on the board
/LR14: U24.5 (O2); also elsewhere on the board
/LR15: U24.7 (O3); also elsewhere on the board
/LR16: U24.9 (O4); also elsewhere on the board
/LR17: U24.11 (O5); also elsewhere on the board
/LR18: U24.13 (O6); also elsewhere on the board
/LR19: U27.9 (O4); also elsewhere on the board
/LR20: U27.11 (O5); also elsewhere on the board
/LR21: U27.13 (O6); also elsewhere on the board
/Left LED Control 13-18/Q0: U15.2 (Q0), U21.14 (I6)
/Left LED Control 13-18/Q1: U15.5 (Q1), U21.12 (I5)
/Left LED Control 13-18/Q2: U15.7 (Q2), U21.10 (I4)
/Left LED Control 13-18/Q3: U15.10 (Q3), U21.6 (I3)
/Left LED Control 13-18/Q4: U15.12 (Q4), U21.4 (I2)
/Left LED Control 13-18/Q5: U15.15 (Q5), U21.2 (I1)
/Right LED Control 1-6/Q0: U16.2 (Q0), U22.14 (I6)
/Right LED Control 1-6/Q1: U16.5 (Q1), U22.12 (I5)
/Right LED Control 1-6/Q2: U16.7 (Q2), U22.10 (I4)
/Right LED Control 1-6/Q3: U16.10 (Q3), U22.6 (I3)
/Right LED Control 1-6/Q4: U16.12 (Q4), U22.4 (I2)
/Right LED Control 1-6/Q5: U16.15 (Q5), U22.2 (I1)
/Right LED Control 7-12/Q0: U17.2 (Q0), U23.14 (I6)
/Right LED Control 7-12/Q1: U17.5 (Q1), U23.12 (I5)
/Right LED Control 7-12/Q2: U17.7 (Q2), U23.10 (I4)
/Right LED Control 7-12/Q3: U17.10 (Q3), U23.6 (I3)
/Right LED Control 7-12/Q4: U17.12 (Q4), U23.4 (I2)
/Right LED Control 7-12/Q5: U17.15 (Q5), U23.2 (I1)
/Right LED Control 13-18/Q0: U18.2 (Q0), U24.14 (I6)
/Right LED Control 13-18/Q1: U18.5 (Q1), U24.12 (I5)
/Right LED Control 13-18/Q2: U18.7 (Q2), U24.10 (I4)
/Right LED Control 13-18/Q3: U18.10 (Q3), U24.6 (I3)
/Right LED Control 13-18/Q4: U18.12 (Q4), U24.4 (I2)
/Right LED Control 13-18/Q5: U18.15 (Q5), U24.2 (I1)
/Thumb LED Control/Q0: U26.2 (Q0), U27.14 (I6)
/Thumb LED Control/Q1: U26.5 (Q1), U27.12 (I5)
/Thumb LED Control/Q2: U26.7 (Q2), U27.10 (I4)
/Thumb LED Control/Q3: U26.10 (Q3), U27.6 (I3)
/Thumb LED Control/Q4: U26.12 (Q4), U27.4 (I2)
/Thumb LED Control/Q5: U26.15 (Q5), U27.2 (I1)
GND: U13.8 (GND), U15.8 (GND), U16.8 (GND), U17.8 (GND), U18.8 (GND), U20.8 (GND), U21.8 (GND), U22.8 (GND), U23.8 (GND), U24.8 (GND), U26.8 (GND), U27.8 (GND); also elsewhere on the board
LED_DIM: U20.1 (E1), U20.15 (E2), U21.1 (E1), U21.15 (E2), U22.1 (E1), U22.15 (E2), U23.1 (E1), U23.15 (E2), U24.1 (E1), U24.15 (E2), U27.1 (E1), U27.15 (E2); also elsewhere on the board
LED_RST: U13.1 (~Mr), U15.1 (~Mr), U16.1 (~Mr), U17.1 (~Mr), U18.1 (~Mr), U26.1 (~Mr); also elsewhere on the board
U13_CLK: U13.9 (Cp); also elsewhere on the board
U15_CLK: U15.9 (Cp); also elsewhere on the board
U16_CLK: U16.9 (Cp); also elsewhere on the board
U17_CLK: U17.9 (Cp); also elsewhere on the board
U18_CLK: U18.9 (Cp); also elsewhere on the board
U26_CLK: U26.9 (Cp); also elsewhere on the board

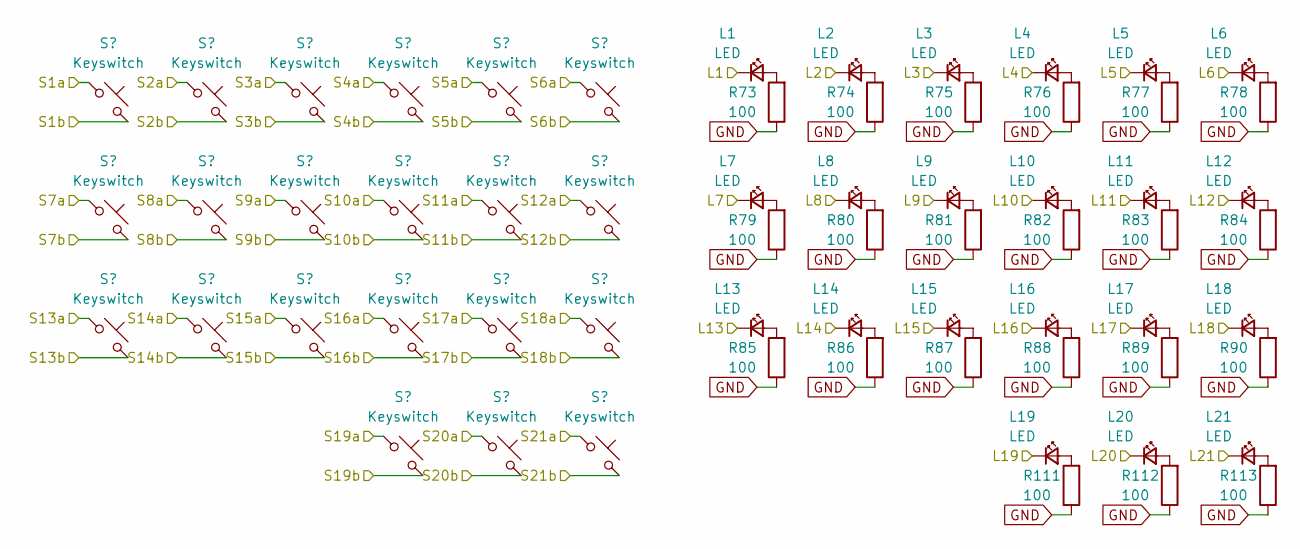
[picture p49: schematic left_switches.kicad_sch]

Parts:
L1, L2, L3, L4, L5, L6, L7, L8, L9, L10, L11, L12, L13, L14, L15, L16, L17, L18, L19, L20, L21: LED; LED_0603_1608Metric
R73, R74, R75, R76, R77, R78, R79, R80, R81, R82, R83, R84, R85, R86, R87, R88, R89, R90, R111, R112, R113: 100; R_0805_2012Metric
S1, S2, S3, S4, S5, S6, S7, S8, S9, S10, S11, S12, S13, S14, S15, S16, S17, S18, S19: Keyswitch; Choc_V1_LED_1.00u
S20, S21: Keyswitch; Choc_V1_LED_1.50u_90deg

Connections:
/LL2: L2.1 (K); also elsewhere on the board
/LL3: L3.1 (K); also elsewhere on the board
/LL4: L4.1 (K); also elsewhere on the board
/LL5: L5.1 (K); also elsewhere on the board
/LL6: L6.1 (K); also elsewhere on the board
/LL7: L7.1 (K); also elsewhere on the board
/LL8: L8.1 (K); also elsewhere on the board
/LL9: L9.1 (K); also elsewhere on the board
/LL10: L10.1 (K); also elsewhere on the board
/LL11: L11.1 (K); also elsewhere on the board
/LL12: L12.1 (K); also elsewhere on the board
/LL13: L13.1 (K); also elsewhere on the board
/LL14: L14.1 (K); also elsewhere on the board
/LL15: L15.1 (K); also elsewhere on the board
/LL16: L16.1 (K); also elsewhere on the board
/LL17: L17.1 (K); also elsewhere on the board
/LL18: L18.1 (K); also elsewhere on the board
/LL19: L19.1 (K); also elsewhere on the board
/LL20: L20.1 (K); also elsewhere on the board
/LL21: L21.1 (K); also elsewhere on the board
/S1a: S1.1; also elsewhere on the board
/S2a: S2.1; also elsewhere on the board
/S3a: S3.1; also elsewhere on the board
/S4a: S4.1; also elsewhere on the board
/S5a: S5.1; also elsewhere on the board
/S6a: S6.1; also elsewhere on the board
/S7a: S7.1; also elsewhere on the board
/S8a: S8.1; also elsewhere on the board
/S9a: S9.1; also elsewhere on the board
/S10a: S10.1; also elsewhere on the board
/S11a: S11.1; also elsewhere on the board
/S12a: S12.1; also elsewhere on the board
/S13a: S13.1; also elsewhere on the board
/S14a: S14.1; also elsewhere on the board
/S15a: S15.1; also elsewhere on the board
/S16a: S16.1; also elsewhere on the board
/S17a: S17.1; also elsewhere on the board
/S18a: S18.1; also elsewhere on the board
/S19a: S19.1; also elsewhere on the board
/S20a: S20.1; also elsewhere on the board
/S21a: S21.1; also elsewhere on the board
GND: R73.1, R74.1, R75.1, R76.1, R77.1, R78.1, R79.1, R80.1, R81.1, R82.1, R83.1, R84.1, R85.1, R86.1, R87.1, R88.1, R89.1, R90.1, R111.1, R112.1, R113.1, S1.2, S2.2, S3.2, S4.2, S5.2, S6.2, S7.2, S8.2, S9.2, S10.2, S11.2, S12.2, S13.2, S14.2, S15.2, S16.2, S17.2, S18.2, S19.2, S20.2, S21.2; also elsewhere on the board
unnamed: L1.2 (A), R73.2
unnamed: L2.2 (A), R74.2
unnamed: L3.2 (A), R75.2
unnamed: L4.2 (A), R76.2
unnamed: L5.2 (A), R77.2
unnamed: L6.2 (A), R78.2
unnamed: L7.2 (A), R79.2
unnamed: L8.2 (A), R80.2
unnamed: L9.2 (A), R81.2
unnamed: L10.2 (A), R82.2
unnamed: L11.2 (A), R83.2
unnamed: L12.2 (A), R84.2
unnamed: L13.2 (A), R85.2
unnamed: L14.2 (A), R86.2
unnamed: L15.2 (A), R87.2
unnamed: L16.2 (A), R88.2
unnamed: L17.2 (A), R89.2
unnamed: L18.2 (A), R90.2
unnamed: L19.2 (A), R111.2
unnamed: L20.2 (A), R112.2
unnamed: L21.2 (A), R113.2

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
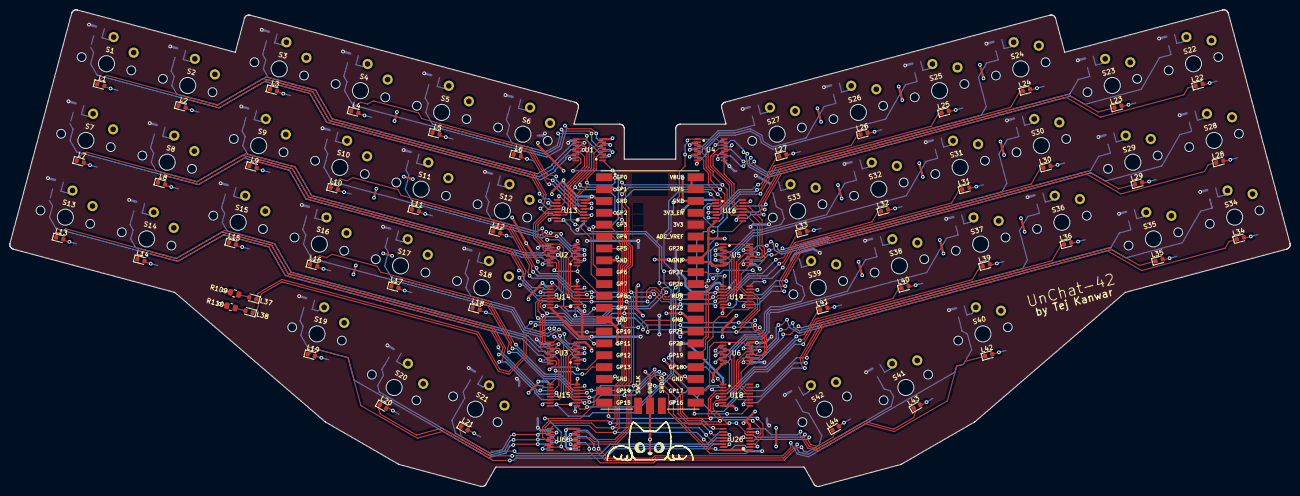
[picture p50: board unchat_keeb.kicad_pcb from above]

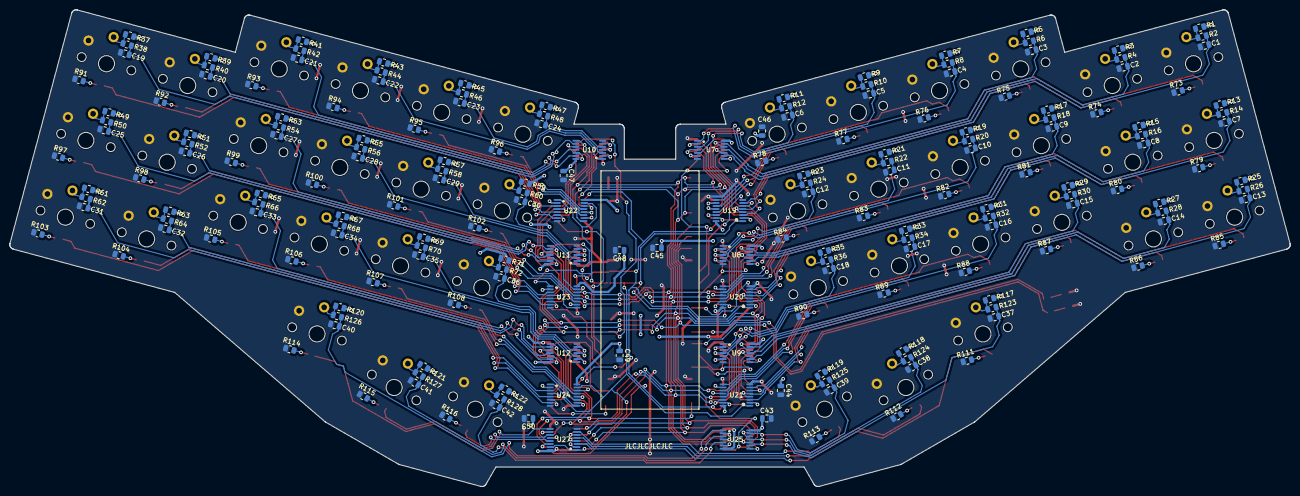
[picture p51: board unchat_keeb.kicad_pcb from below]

Board: 2 copper layers, 274.0 x 102.0 mm, 293 parts (190 on the bottom side), 281 nets.

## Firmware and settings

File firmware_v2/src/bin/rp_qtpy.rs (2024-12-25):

#![no_std]
#![no_main]

// choice of Board Support Package
// use rp_pico as bsp;
use adafruit_qt_py_rp2040 as bsp;

use bsp::entry;
use bsp::hal::{
  self,
  adc,
  clocks::{init_clocks_and_plls, Clock, ClocksManager},
  pac::{self, interrupt},
  pio::{self, PIOExt},
  gpio,
  sio,
  timer,
  watchdog
};
use cortex_m as cpu;
use cortex_m::interrupt::Mutex;
use ehal::digital::v2::{InputPin, OutputPin, PinState};
use ehal::adc::OneShot;
use ws2812_pio::Ws2812Direct;
use smart_leds::{SmartLedsWrite, RGB8};

use core::convert::Infallible;
use core::panic::PanicInfo;
use core::cell::Cell;
use core::fmt::{self, Write};
use heapless::Vec;

use usb_device::{
  prelude::*,
  class_prelude::*,
  // descriptor::lang_id::LangID,
};
use usbd_hid::{
  hid_class, descriptor::generator_prelude::*
};
use usbd_serial::{
  SerialPort,
  embedded_io::{Write as EWrite, ReadReady},
};

use keeb::{
  prelude::*,
  error::Error,
  layout::Keymap,
  board::Board,
  bus::AnalogBus,
  usb::NKROBootKeyboardReport,
  switch_matrix::SwitchMatrix,
  vkeyboard::VKeyboard,
};

enum NpState {
  Off, Ok, Panic,
}

fn get_np_color(state: NpState) -> RGB8 {
  match state {
    NpState::Off => (0, 0, 0).into(),
    NpState::Ok => (50, 0, 50).into(),
    NpState::Panic => (75, 0, 0).into(),
  }
}

#[panic_handler]
fn panic(info: &PanicInfo) -> ! {
  // set panic led
  set_neopixel(NpState::Panic);
  // write panic info to serial repeatedly
  let mut buf = WriteBuf::<1024>::new();
  write!(&mut buf, "Panic: {}\r\n", info).ok();
  loop {
    for chunk in buf.data[..].chunks(128) {
      write_serial(chunk);
      drain_serial();
    }
    safe_delay_ms(200);
    set_neopixel(NpState::Off);
    safe_delay_ms(800);
    set_neopixel(NpState::Panic);
  }
}

fn write_serial(buf: &[u8]) {
  cpu::interrupt::free(|cs| {
    let mut usb_interface = Cell::new(None);
    mutex_usb_interface.borrow(cs).swap(&usb_interface);
    match usb_interface.get_mut() {
      Some(UsbInterface{ usb_serial_class, .. }) => {
        usb_serial_class.write(buf).ok();
      },
      _ => {}
    };
    mutex_usb_interface.borrow(cs).swap(&usb_interface);
  });
}

fn write_fmt_serial(fmt: fmt::Arguments) {
  cpu::interrupt::free(|cs| {
    let mut usb_interface = Cell::new(None);
    mutex_usb_interface.borrow(cs).swap(&usb_interface);
    match usb_interface.get_mut() {
      Some(UsbInterface{ usb_serial_class, .. }) => {
        usb_serial_class.write_fmt(fmt).ok();
      },
      _ => {}
    };
    mutex_usb_interface.borrow(cs).swap(&usb_interface);
  });
}

fn drain_serial() {
  cpu::interrupt::free(|cs| {
    let mut buf: [u8; 1024] = [0; 1024];
    let mut usb_interface = Cell::new(None);
    mutex_usb_interface.borrow(cs).swap(&usb_interface);
    match usb_interface.get_mut() {
      Some(UsbInterface{ usb_serial_class, .. }) => {
        usb_serial_class.read(&mut buf[..]).ok();
      },
      _ => {}
    };
    mutex_usb_interface.borrow(cs).swap(&usb_interface);
  });
}

fn grab_delay() -> Cell<Option<cpu::delay::Delay>> {
  cpu::interrupt::free(|cs| {
    let delay_cell = Cell::new(None);
    mutex_delay.borrow(cs).swap(&delay_cell);
    return delay_cell;
  })
}

fn return_delay(delay: Cell<Option<cpu::delay::Delay>>) {
  cpu::interrupt::free(|cs| {
    mutex_delay.borrow(cs).swap(&delay);
  });
}

fn safe_delay_ms(ms: u32) {
  let mut delay_cell = grab_delay();
  match delay_cell.get_mut() {
    Some(delay) => delay.delay_ms(ms),
    None => panic!("Missing delay timer"),
  };
  return_delay(delay_cell);
}

fn set_neopixel(state: NpState) {
  cpu::interrupt::free(|cs| {
    let mut neopixel = Cell::new(None);
    mutex_neopixel.borrow(cs).swap(&neopixel);
    match neopixel.get_mut() {
      Some(Neopixel { power, control }) => {
        control.write([get_np_color(state)].iter().copied()).unwrap_or(());
      },
      _ => {}
    }
    mutex_neopixel.borrow(cs).swap(&neopixel);
  });
}

type PinOut = gpio::FunctionSio<gpio::SioOutput>;
type PinIn = gpio::FunctionSio<gpio::SioInput>;
type PinPD = gpio::PullDown;
type PinFloat = gpio::PullNone;
type PinA0 = gpio::Pin<gpio::bank0::Gpio29, PinIn, PinFloat>;
type PinA1 = gpio::Pin<gpio::bank0::Gpio28, PinIn, PinFloat>;
type PinA2 = gpio::Pin<gpio::bank0::Gpio27, PinIn, PinFloat>;
type PinA3 = gpio::Pin<gpio::bank0::Gpio26, PinIn, PinFloat>;

struct GpioIn {
  pin: gpio::Pin<gpio::DynPinId, PinIn, PinPD>
}
impl GpioIn {
  fn new<I: gpio::PinId, F: gpio::Function, P: gpio::PullType>(
    pin: gpio::Pin<I, F, P>) -> Self
  where I: gpio::ValidFunction<PinIn> {
    Self {
      pin: pin.into_pull_down_input().into_dyn_pin()
    }
  }
}

struct GpioOut {
  pin: gpio::Pin<gpio::DynPinId, PinOut, PinPD>
}
impl GpioOut {
  fn new<I: gpio::PinId, F: gpio::Function, P: gpio::PullType>(
    pin: gpio::Pin<I, F, P>) -> Self
  where I: gpio::ValidFunction<PinOut> {
    Self {
      pin: pin.into_push_pull_output().into_pull_type().into_dyn_pin()
    }
  }
}

impl InputPin for GpioIn {
  type Error = Infallible;
  fn is_high(&self) -> Result<bool, Self::Error> {
    self.pin.is_high()
  }
  fn is_low(&self) -> Result<bool, Self::Error> {
    self.pin.is_low()
  }
}

impl TryIntoOutputPin for GpioIn {
  type Pin = GpioOut;
  fn try_into_output_pin(self) -> Result<Self::Pin, Error> {
    match self.pin.try_into_function::<PinOut>() {
      Ok(pin) => Ok(Self::Pin { pin }),
      Err(_) => Err(Error::PinConfigError)
    }
  }
}

impl OutputPin for GpioOut {
  type Error = Infallible;
  fn set_low(&mut self) -> Result<(), Self::Error> {
    self.pin.set_low()
  }
  fn set_high(&mut self) -> Result<(), Self::Error> {
    self.pin.set_high()
  }
}


impl TryIntoInputPin for GpioOut {
  type Pin = GpioIn;
  fn try_into_input_pin(self) -> Result<Self::Pin, Error> {
    match self.pin.try_into_function::<PinIn>() {
      Ok(pin) => Ok(Self::Pin { pin }),
      Err(_) => Err(Error::PinConfigError)
    }
  }
}

type NeopixelControlPin = gpio::Pin<gpio::DynPinId, gpio::FunctionPio0, gpio::PullNone>;
struct Neopixel {
  power: GpioOut,
  control: Ws2812Direct<pac::PIO0, pio::SM0, NeopixelControlPin>,
}

struct UserPins {
  neopixel: Neopixel,
  analog_pins: (PinA0, PinA1, PinA2, PinA3),
  general_pins: Vec<GpioIn, 32>,
  general_ids: Vec<usize, 32>,
}

fn into_user_pins<'timer, C: Clock>(
  pins: hal::gpio::bank0::Pins, pio0: &mut pio::PIO<pac::PIO0>,
  sm0: pio::UninitStateMachine<pio::PIO0SM0>, clock: &C)
  -> UserPins
{
  let neopixel = Neopixel {
    power: GpioOut {
      pin: pins.gpio11.into_push_pull_output_in_state(gpio::PinState::High).into_dyn_pin()
    },
    control: Ws2812Direct::new(
      pins.gpio12.into_function().into_pull_type::<gpio::PullNone>().into_dyn_pin(),
      pio0,
      sm0,
      clock.freq(),
    ),
  };
  UserPins {
    neopixel,
    analog_pins: (
      pins.gpio29.into_floating_input(),
      pins.gpio28.into_floating_input(),
      pins.gpio27.into_floating_input(),
      pins.gpio26.into_floating_input(),
    ),
    general_pins: [
      GpioIn::new(pins.gpio0),
      GpioIn::new(pins.gpio1),
      GpioIn::new(pins.gpio2),
      GpioIn::new(pins.gpio3),
      GpioIn::new(pins.gpio4),
      GpioIn::new(pins.gpio5),
      GpioIn::new(pins.gpio6),
      GpioIn::new(pins.gpio7),
      GpioIn::new(pins.gpio8),
      GpioIn::new(pins.gpio9),
      GpioIn::new(pins.gpio10),
      GpioIn::new(pins.gpio13),
      GpioIn::new(pins.gpio14),
      GpioIn::new(pins.gpio15),
      GpioIn::new(pins.gpio16),
      GpioIn::new(pins.gpio17),
      GpioIn::new(pins.gpio18),
      GpioIn::new(pins.gpio19),
      GpioIn::new(pins.gpio20),
      GpioIn::new(pins.gpio21),
      GpioIn::new(pins.gpio22),
      GpioIn::new(pins.gpio23),
      GpioIn::new(pins.gpio24),
      GpioIn::new(pins.gpio25),
    ].into_iter().collect(),
    general_ids: [
      0, 1, 2, 3, 4, 5, 6, 7, 8, 9, 10, 13, 14, 15, 16,
      17, 18, 19, 20, 21, 22, 23, 24, 25,
    ].into_iter().collect(),
  }
}

struct AdcBus {
  pins: (adc::AdcPin<PinA0>, adc::AdcPin<PinA1>, adc::AdcPin<PinA2>, adc::AdcPin<PinA3>),
  adc: adc::Adc,
}

impl AnalogBus for AdcBus {
  fn read(&mut self) -> RegValue {
    [
      self.adc.read(&mut self.pins.0).unwrap_or(0),
      self.adc.read(&mut self.pins.1).unwrap_or(0),
      self.adc.read(&mut self.pins.2).unwrap_or(0),
      self.adc.read(&mut self.pins.3).unwrap_or(0),
    ]
  }
}

type UsbBusAlloc = UsbBusAllocator<hal::usb::UsbBus>;
type UsbDev<'a> = UsbDevice<'a, hal::usb::UsbBus>;
type UsbKbdClass<'a> = hid_class::HIDClass<'a, hal::usb::UsbBus>;
type UsbSerialClass<'a> = SerialPort<'a, hal::usb::UsbBus>;
struct UsbInterface<'a> {
  usb_dev: UsbDev<'a>,
  usb_kbd_class: UsbKbdClass<'a>,
  usb_serial_class: UsbSerialClass<'a>,
}

static mutex_usb_interface: Mutex<Cell<Option<UsbInterface>>>
  = Mutex::new(Cell::new(None));
static mutex_neopixel: Mutex<Cell<Option<Neopixel>>>
  = Mutex::new(Cell::new(None));
// delay timer must be global for panic handler
static mutex_delay: Mutex<Cell<Option<cpu::delay::Delay>>>
  = Mutex::new(Cell::new(None));

#[allow(non_snake_case)]
#[interrupt]
unsafe fn USBCTRL_IRQ() {
  cpu::interrupt::free(|cs| {
    let mut usb_interface = Cell::new(None);
    mutex_usb_interface.borrow(cs).swap(&usb_interface);
    match usb_interface.get_mut() {
      Some(UsbInterface{ usb_dev, usb_kbd_class, usb_serial_class, .. }) => {
        usb_dev.poll(&mut [usb_kbd_class, usb_serial_class]);
      },
      _ => {}
    }
    mutex_usb_interface.borrow(cs).swap(&usb_interface);
  });
}

// generic keyboard
// https://github.com/obdev/v-usb/blob/master/usbdrv/USB-IDs-for-free.txt
const USB_VID_PID_GEN_KBD: UsbVidPid = UsbVidPid(0x16c0, 0x27db);
// USB poll bInterval [1-255]
const USB_POLL_MS: u8 = 1;

#[entry]
fn rp2040_main() -> ! {
  // usb bus must be static lifetime for interrupts
  static mut USB_BUS: Option<UsbBusAlloc> = None;

  // init board state and components
  let mut pac = pac::Peripherals::take().unwrap();
  let core = pac::CorePeripherals::take().unwrap();
  let mut watchdog = watchdog::Watchdog::new(pac.WATCHDOG);
  let sio = sio::Sio::new(pac.SIO);
  const XTAL_FREQ_HZ: u32 = 12_000_000_u32;
  let clocks = init_clocks_and_plls(
    XTAL_FREQ_HZ, pac.XOSC, pac.CLOCKS, pac.PLL_SYS, pac.PLL_USB,
    &mut pac.RESETS, &mut watchdog).unwrap();
  let delay = cpu::delay::Delay::new(core.SYST, clocks.system_clock.freq().to_Hz());
  let mut delay_cell = Cell::new(Some(delay));
  return_delay(delay_cell);
  let adc = adc::Adc::new(pac.ADC, &mut pac.RESETS);
  let pins = hal::gpio::bank0::Pins::new(
    pac.IO_BANK0,
    pac.PADS_BANK0,
    sio.gpio_bank0,
    &mut pac.RESETS,
  );
  let (mut pio0, sm0, _, _, _) = pac.PIO0.split(&mut pac.RESETS);
  let timer = timer::Timer::new(pac.TIMER, &mut pac.RESETS, &clocks);

  // split up pins, init neopixel for diagnostics
  let mut user_pins = into_user_pins(pins, &mut pio0, sm0, &clocks.peripheral_clock);
  user_pins.neopixel.control.write([get_np_color(NpState::Ok)].iter().copied()).unwrap();
  let neopixel = Cell::new(Some(user_pins.neopixel));
  cpu::interrupt::free(|cs| {
    mutex_neopixel.borrow(cs).swap(&neopixel);
  });

  // set up USB
  *USB_BUS = Some(UsbBusAllocator::new(hal::usb::UsbBus::new(
    pac.USBCTRL_REGS, pac.USBCTRL_DPRAM, clocks.usb_clock, true, &mut pac.RESETS
  )));
  let usb_bus = USB_BUS.as_ref().unwrap();
  let desc = NKROBootKeyboardReport::desc();
  let usb_kbd_class = hid_class::HIDClass::new_with_settings(
    &usb_bus, desc, USB_POLL_MS,
    hid_class::HidClassSettings {
      subclass: hid_class::HidSubClass::NoSubClass,
      protocol: hid_class::HidProtocol::Keyboard,
      config: hid_class::ProtocolModeConfig::DefaultBehavior,
      locale: hid_class::HidCountryCode::US,
    });
  let usb_serial = SerialPort::new(&usb_bus);
  let str_desc = StringDescriptors::new(LangID::EN)
    .manufacturer("gkanwar")
    .product("Unchat-40")
    .serial_number("XXXX");
  let usb_dev =
    UsbDeviceBuilder::new(&usb_bus, USB_VID_PID_GEN_KBD)
    .strings(&[str_desc]).map_err(|_| Error::UsbError).unwrap()
    // .composite_with_iads()
    .device_class(0x00) // composite
    .build();
  let usb_interface = Cell::new(Some(UsbInterface {
    usb_dev, usb_kbd_class, usb_serial_class: usb_serial
  }));
  cpu::interrupt::free(|cs| {
    mutex_usb_interface.borrow(cs).swap(&usb_interface);
  });
  // USB interrupts
  unsafe {
    pac::NVIC::unmask(pac::Interrupt::USBCTRL_IRQ);
  }

  write_serial(b"Unchat-40 firmware loading...\r\n");

  // load keymap
  let (keymap, _bytes_read): (Keymap, usize) =
    serde_json::from_slice(include_bytes!("../../keymaps/split-40-colemak-callum.json"))
    .unwrap();
  let layout = keeb::layout::get_layout(keymap.layout);
  write_serial(b"Loaded keymap.\r\n");

  // load board
  let (board, _bytes_read): (Board, usize) =
    serde_json::from_slice(include_bytes!("../../boards/unchat-40.json"))
    .unwrap();
  write_serial(b"Loaded board config.\r\n");

  let board_pins =
    keeb::board::split_pins(user_pins.general_pins, user_pins.general_ids, &board).unwrap();
  if user_pins.analog_pins.0.id().num != board.bus_pins[0]
    || user_pins.analog_pins.1.id().num != board.bus_pins[1]
    || user_pins.analog_pins.2.id().num != board.bus_pins[2]
    || user_pins.analog_pins.3.id().num != board.bus_pins[3] {
      panic!("Board bus pins mismatch");
  }
  let mut bus = AdcBus {
    pins: (
      adc::AdcPin::new(user_pins.analog_pins.0).unwrap_or_else(|_| panic!()),
      adc::AdcPin::new(user_pins.analog_pins.1).unwrap_or_else(|_| panic!()),
      adc::AdcPin::new(user_pins.analog_pins.2).unwrap_or_else(|_| panic!()),
      adc::AdcPin::new(user_pins.analog_pins.3).unwrap_or_else(|_| panic!()),
    ),
    adc,
  };

  let reg_map = keeb::board::make_reg_map(&board, &layout);
  let mut switches = SwitchMatrix::<GpioOut>::new(
    reg_map.clone(), board_pins.sel_pins).unwrap();
  let mut vkbd = VKeyboard::new(keymap).unwrap();
  write_serial(b"Established switch matrix and virtual keyboard.\r\n");
  write_serial(b"Running main loop.\r\n");

  let mut buf: [u8; 64] = [0; 64]; // for usb OUT packets
  let mut pending = false;
  loop {
    let mut delay_cell = grab_delay();
    let delay = match delay_cell.get_mut() {
      Some(delay) => delay,
      None => panic!("missing delay"),
    };
    delay.delay_ms(1);
    // let mut log_buf = WriteBuf::<4196>::new();
    let (updated, new_bus) = keeb::tick(
      bus, &mut switches, &mut vkbd, delay, |args: fmt::Arguments<'_>| {
        // write_fmt_serial(args);
      }
    ).unwrap();
    // write_serial(&log_buf.data[..]);
    bus = new_bus;
    return_delay(delay_cell);

    if vkbd.reset {
      hal::rom_data::reset_to_usb_boot(0, 0);
    }

    let report = if updated || pending {
      // write_fmt_serial(format_args!("Kbd keys: {:?}\r\n", vkbd.get_report().nkro_keys));
      Some(vkbd.get_report().clone())
    }
    else {
      None
    };

    
    cpu::interrupt::free(|cs| {
      let mut usb_interface = Cell::new(None);
      mutex_usb_interface.borrow(cs).swap(&usb_interface);
      let configured = match usb_interface.get_mut() {
        Some(UsbInterface{ usb_dev, .. }) =>
          usb_dev.state() == UsbDeviceState::Configured,
        None => false,
      };
      if configured {
        match usb_interface.get_mut() {
          Some(UsbInterface{ usb_kbd_class, usb_serial_class, .. }) => {
            match usb_kbd_class.pull_raw_output(&mut buf) {
              Ok(size) => {},
              Err(UsbError::WouldBlock) => {}, // no data
              Err(err) => panic!("unexpected read error"),
            }
            match report {
              Some(mut report) => {
                match usb_kbd_class.get_protocol_mode() {
                  Ok(hid_class::HidProtocolMode::Report) => {
                    for i in 0..report.boot_keys.len() {
                      report.boot_keys[i] = 0;
                    }
                  }
                  _ => {}
                }
                match usb_kbd_class.push_input(&report) {
                  Ok(size) => {
                    pending = false;
                  },
                  Err(UsbError::WouldBlock) => { // buffer full
                    pending = true;
                  },
                  // usbd-hid bug: error on protocol `Report` with subclass `Boot`
                  // hack: forcibly set protocol mode to Boot :(
                  Err(UsbError::InvalidState) => {
                    pending = true;
                    let protocol = usb_kbd_class.get_protocol_mode();
                    if let Ok(protocol) = protocol {
                      usb_kbd_class.set_protocol_mode(
                        protocol, hid_class::ProtocolModeConfig::ForceBoot).unwrap();
                    }
                  },
                  Err(err) => panic!("unexpected write error"),
                }
              }
              None => {}
            }
            // get serial input
            if usb_serial_class.read_ready().unwrap_or(false) {
              let mut buf: [u8; 128] = [0; 128];
              match usb_serial_class.read(&mut buf[..]) {
                Ok(n) => {
                  // FORNOW: echo messages
                  usb_serial_class.write(&buf[..n]).ok();
                  usb_serial_class.flush().ok();
                }
                Err(UsbError::WouldBlock) => {}
                Err(_) => {
                  usb_serial_class.write(b"X\r\n").ok();
                }
              }
            }
          },
          None => {},
        }
      }
      mutex_usb_interface.borrow(cs).swap(&usb_interface);
    });
  }

  // // pause, then reboot into BOOTSEL
  // safe_delay_ms(1000);
  // hal::rom_data::reset_to_usb_boot(0, 0);
  // unreachable!();
}

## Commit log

2023-12-10 Initialize repo with basic PCB design and libraries
    [bottom_plate.dxf, bottom_plate.scad, debounce.kicad_sch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]
2023-12-17 Add extra columns, updating to 42-key design
    [debounce.kicad_sch, led_control.kicad_sch, left_switches.kicad_sch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]
2023-12-22 Add dxf layout and finish half keyboard pbc layout
    [choc_v1.scad, debounce.kicad_sch, layout.scad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]
2023-12-23 Position right switches, update dxf dims, and fix symb lib paths
    [layout.scad, pcb.dxf, switches.dxf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]
2023-12-24 Route remaining components, except VCC and GND
    [layout.scad, pcb.dxf, unchat_keeb.kicad_pcb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]
2023-12-24 Add custom footprints with fixed courtyards
2023-12-24 Finalize the board
    [debounce.kicad_sch, led_control.kicad_sch, unchat_keeb.kicad_pcb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]
2023-12-25 Add bus pullups, still need to route 'em
    [unchat_keeb.kicad_pcb, unchat_keeb.kicad_sch]
2023-12-25 Remove pullups, as RPi GPIOs are pulled by default
    [unchat_keeb.kicad_pcb, unchat_keeb.kicad_sch]
2023-12-26 Add JLCPCB production files
    v0.2: last-minute rotation to thumb switches
    [bom.csv, designators.csv, positions.csv]
2023-12-28 board: Add rendered schematics for easy access
2024-01-01 firmware: Add basic USB keyboard device stack
2024-01-03 docs: Add PCB design guidelines
2024-01-09 firmware: Fix basic problems
    It (mostly) works!!
    [rp_pico.rs]
2024-01-10 firmware: Add rp2040-e5 feature flag
    My boards use RP2040-B1 which is affected by this erratum.
2024-01-10 firmware: Add delays for timing on switch reads
2024-01-10 firmware: Fix updated early-return bug
    Keys actually type extremely reliably now!!! Amazing.
    [rp_pico.rs]
2024-01-11 firmware: Fix USB poll rate and packet spam
    [rp_pico.rs]
2024-02-25 firmware: Fix padding bug and osx quirks
    [rp_pico.rs]
2024-11-17 Unchat-40: Kicad project and CAD design for top/bottom plates
    [4600 QTPy.step.stl, adafruit_qt_py.scad, bom.csv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]
2024-11-30 firmware v2: Basic impl with most core functionality
    * Scanning all 16 analog registers with associative map to switch matrix
    * Hysteresis for key up/down triggers
    * Neopixel control
    * Serial over USB with logging, including on panics
2024-12-01 readme: Added with many images and a snippet of the timelapse
    [debounce.kicad_sch, layout.scad, led_control.kicad_sch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]
2024-12-25 firmware v2: Fix serial rendering bug, clean up layout and usb impl
    [rp_qtpy.rs]
